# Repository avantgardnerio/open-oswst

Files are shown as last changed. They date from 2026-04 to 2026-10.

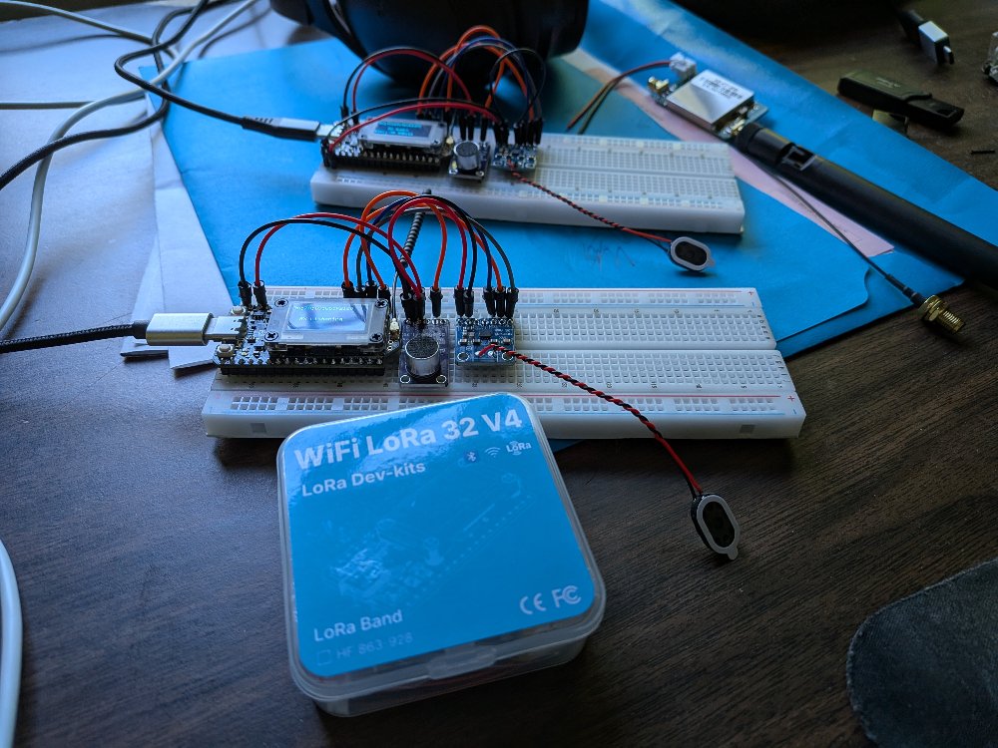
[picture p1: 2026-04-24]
docs/simplex-duo.jpg

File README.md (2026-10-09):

# open-oswst

Stealth LoRa radio mesh where the primary design principle is "only speak when spoken to": a simplex push-to-talk voice radio over
LoRa, with flood repeaters, that transmits nothing until someone presses PTT.

open-oswst radio in 3d printed case

## Hardware

- **Board**: [Heltec WiFi LoRa 32 V4.3](https://heltec.org/project/wifi-lora-32-v4/) (ESP32-S3 + SX1262, 863-928 MHz)
- **MCU**: ESP32-S3 rev 0.2, 16MB flash, ~380 KiB RAM, no PSRAM
- **Radio**: Semtech SX1262 LoRa transceiver, 915 MHz ISM band, behind the board's KCT8103L front-end module (PA + LNA), then an
  external "Air Buddy" amplifier. The SX1262 runs at 6 dBm, which should give roughly 1 W out of the Air Buddy (estimated from datasheets,
  not measured)
- **GPS**: L76K on the Heltec's GNSS connector (UTC time and position, logged and shown on screen)
- **Display**: SSD1306 128x64 OLED (I2C)
- **Audio**: MAX9814 electret mic (ADC), MAX98357A I2S class-D speaker amp

The board is a V4.3. All the boards we've tested are; a V4.2 (GC1109 front end) would need different FEM pins and TX power.

### Pin Map

`src/board.rs` is the one place pins are assigned; this table mirrors it.

| Function | GPIO | Notes |
|---|---|---|
| PTT (PRG button) | 0 | Active LOW, internal pull-up |
| VOL encoder A / B / SW | 3 / 6 / 45 | GPIO45 is a strapping pin, safe as a switch to GND |
| Mic (ADC1) | 4 | MAX9814 out |
| Speaker I2S BCLK / DIN / WS | 47 / 33 / 48 | MAX98357A |
| OLED SDA / SCL / RST | 17 / 18 / 21 | |
| Vext power enable | 36 | LOW = on (OLED) |
| LoRa SCK / MOSI / MISO / NSS | 9 / 10 / 11 / 8 | SPI2 |
| LoRa RST / DIO1 / BUSY | 12 / 14 / 13 | |
| FEM power / enable (CSD) | 7 / 2 | Held HIGH while running |
| FEM CTX | 5 | HIGH only during TX (LOW = RX through the LNA) |
| GPS UART RX / TX | 39 / 38 | ESP side. Meshtastic's variant file comments have these the other way round |
| GPS power / reset / wake | 34 / 42 / 40 | Power is active LOW |
| Battery sense | 1 (+ 37 enables the divider) | Free for this on the newest PCB rev; not used by the firmware yet |

## Dev Environment Setup

### Prerequisites

1. **Install Rust + Xtensa toolchain** via [espup](https://github.com/esp-rs/espup):

```bash
cargo install espup
espup install
```

2. **Create an ESP environment export script** (`~/export-esp.sh`):

```bash
export LIBCLANG_PATH="$HOME/.rustup/toolchains/esp/xtensa-esp32-elf-clang/esp-20.1.1_20250829/esp-clang/lib"
export PATH="$HOME/.rustup/toolchains/esp/xtensa-esp-elf/esp-15.2.0_20250920/xtensa-esp-elf/bin:$PATH"
```

The exact paths may vary — check `~/.rustup/toolchains/esp/` after `espup install`.

3. **Install flashing tools**:

```bash
cargo install espflash cargo-espflash ldproxy
```

4. **Python tools** (log pulling, PCB and case generation) live in a venv built with Python 3.13:

```bash
python3.13 -m venv .venv
.venv/bin/pip install -r requirements.txt
```

### Build

```bash
. ~/export-esp.sh
cargo build                      # firmware (repo root, ESP32-S3)
(cd core && cargo test)          # app logic unit tests, on this PC
(cd desktop && cargo run)        # desktop build (a skeleton so far)
```

ESP-IDF v5.5.x is downloaded automatically by `esp-idf-sys` on first build (takes a while).

### Flash

Over USB, use the script. It flashes every connected board at once, and passes the three things a bare `espflash flash` gets wrong:

```bash
. ~/export-esp.sh && cargo build && scripts/flash-all.sh
```

- **our bootloader** (`--bootloader`): it switches the flash to QIO. espflash's bundled one is DIO
- **our partition table** (`--partition-table`): espflash's default drops the `storage` partition and the OTA slots
- **`--erase-parts otadata`**: otherwise a board last updated over WiFi keeps booting the other slot

Over WiFi, see [In the Field](#in-the-field).

Serial ports aren't stable between plug-ins: identify boards by MAC (the ESP32-S3's USB serial number), not by `ttyACM` number. To capture a
boot log from the first line, `python3 scripts/boot-log.py <PORT>`. Never flash while another program holds the port.

### Device Config

Each board's settings are a text file on its storage: `/data/config.toml`. On the newest PCB rev the on-device menu (click the VOL knob)
sets the mode and rewrites the file. Every setting and flag is declared in `core/src/config.rs`; each boot logs their values
and a 4-digit settings profile (also in `/api/status`): radios with different profiles can't hear each other.

```toml
mode = "repeater"        # normal | repeater | echo

[flags]                  # experiments, come and go (core/src/config.rs lists them)

[[wifi]]                 # networks to join, tried in order
ssid = "Starlink"
password = "..."
```

`scripts/provision.py` writes it over USB, from `boards.toml` in the repo root (kept out of git: it holds WiFi passwords; copy
`boards.example.toml` to start). It flashes the firmware too, and **erases the board's storage**, logs included: pull them first.

```bash
.venv/bin/python scripts/provision.py                      # every connected board
.venv/bin/python scripts/provision.py A4:CB:8F:A2:0F:5C    # just this one
```

The boot log shows the result, e.g. `Config: mode=Echo, 1 WiFi network(s)`.

### Logs

Every boot writes a text log to `/data/log/NNNN.txt` on the board's LittleFS `storage` partition (~11.6 MB). Lines are buffered in RAM and
only written to flash after 3 s with no radio traffic, because a flash write stalls the chip for up to ~18 ms. To copy them off a board:

```bash
.venv/bin/python scripts/pull-logs.py <PORT>     # ~80 s; writes logs/<MAC>-<time>/
```

After an echo test, join the handheld's and the echo station's logs into a per-transmission table and a map (OpenStreetMap/satellite,
one circle per transmission coloured by how well each direction got through, plus GeoJSON for QGIS):

```bash
.venv/bin/python scripts/range-report.py <handheld log> <echo station log>
```

## In the Field

Every radio has the field hotspot (Starlink) in its `config.toml` and stays on WiFi, so in the field the laptop does everything over
WiFi: find the radios, read their status and logs, change their config, update their firmware. USB is the fallback.

### Laptop setup (once, at home)

```bash
sudo apt install avahi-utils curl    # avahi-browse finds the radios; Ubuntu resolves *.local out of the box
```

Plus the build tools above (`espup`, `espflash`, `~/export-esp.sh`), so firmware can be built and saved as an image in the field.

### Find the radios

Join the laptop to the same network as the radios, then:

```bash
avahi-browse -rtp _oswst._tcp | grep "^="    # one line per radio: name, host, IP, port
```

Each radio is `oswst-XXXX.local`, from the last 4 hex digits of its MAC (A4:CB:8F:A2:0F:5C is `oswst-0f5c`). A radio joins WiFi ~7 s
after boot. If a radio doesn't show up:

- `getent hosts oswst-0f5c.local`: asks for one radio by name
- check that avahi-browse ran at all. Don't pipe its errors into grep: if it isn't installed, `2>&1 | grep` prints nothing,
  which looks exactly like "no radios"
- last resort, scan the subnet for the API:
  `for i in $(seq 1 254); do curl -s -m 1 http://192.168.0.$i/api/status | grep -q mac && echo 192.168.0.$i & done; wait`

### Talk to a radio

In a browser: `http://oswst-XXXX.local/` (or its IP) opens the radio's web page, its status and a live picture of its screen
(`www/`, served by the radio itself: no internet needed).

Port 80, no password (the WiFi password is the security). `/fs/` is the radio's storage as a read-write WebDAV folder
(`src/webdav.rs`): open `dav://oswst-XXXX.local/fs/` in a file manager, or:

```bash
R=oswst-0f5c.local
curl http://$R/api/status                     # name, MAC, firmware (git hash, confirmed?), OTA slot, mode, uptime, heap
gio list -l dav://$R/fs/log/                  # after `gio mount dav://$R/fs/`
curl -O http://$R/fs/log/0007.txt             # fetch a log: 25 KB in under 0.1 s (vs ~80 s over USB)
curl -O http://$R/fs/config.toml              # the settings
curl -T config.toml http://$R/fs/config.toml  # replace them (checked first: a bad file is refused); apply on reboot
curl -X POST http://$R/api/reboot
curl -X POST http://$R/api/wifi/off           # WiFi off until the next power cycle (for timing-sensitive tests)
```

`/api/wifi/off` isn't saved: every boot starts with WiFi on again, so a power cycle always gets the radio back on the network. Once it's
off, the radio can't be reached over WiFi until then.

### Update firmware over WiFi (OTA)

Build, save an app image, put it on the radio as `/fs/firmware.bin` (an ordinary file: a file manager works too), then
`POST /api/ota`: the radio copies it into its spare slot and reboots into it (back up in ~15 s). `/api/status` then shows the new
git hash, the other slot and `"firmware_state":"pending"`: a new app must run a minute (then `valid`), or the radio goes back to the
old one. `GET /api/firmware` downloads the app a radio is running.

```bash
. ~/export-esp.sh && cargo build
espflash save-image --chip esp32s3 target/xtensa-esp32s3-espidf/debug/open-oswst app.bin
curl -T app.bin http://oswst-0f5c.local/fs/firmware.bin && curl -X POST http://oswst-0f5c.local/api/ota
```

Every radio found:

```bash
for host in $(avahi-browse -rtp _oswst._tcp | grep "^=" | cut -d';' -f7 | sort -u); do
    curl -T app.bin http://$host/fs/firmware.bin && curl -X POST http://$host/api/ota
done
```

### USB fallback

When a radio isn't on WiFi:

- **Flash:** `scripts/flash-all.sh`. It passes our bootloader, our partition table and `--erase-parts otadata`, which a bare
  `espflash flash` gets wrong.
- **Pull logs:** `scripts/pull-logs.py` (~80 s).
- **Watch a boot:** `scripts/boot-log.py`.

Identify boards by MAC, not by `ttyACM` number, and never flash while another program holds the port.

## Management Server

Radios get updates from a management server (`server/`, issue #34) that they dial out to: nothing on a radio listens for it. Every
connection is Noise: a radio must know the server's public key, and the server must find the radio's in its list, or it's refused.
The server's files live in one folder outside the repo (default `/srv/oswst`):

```
server.key      the server's key pair (mode 0600)
radios.toml     the radios allowed in: re-read at every connection, no restart needed
bundle.tar.gz   THE update: radios that don't have it are offered it
```

```bash
cd server && cargo run --release -- keygen /srv/oswst     # once: prints the server's public key
cd server && cargo run --release -- /srv/oswst            # run it (port 3101)
```

### Publish an update

```bash
scripts/publish-firmware.sh          # builds, then writes /srv/oswst/bundle.tar.gz
```

A bundle (`core/src/bundle.rs`) is one `.tar.gz`: `firmware.bin` for the radio's spare app slot, and `www/` (the web page, with
only the `node_modules` files its import map names) for its storage. The server notices the new file by itself.

### Install it

On the radio: **menu, Update**. It shows the version and size, then **Install** runs three steps, each in percent: **Downloading**
(to the storage), **Verifying** (its SHA-256), **Extracting** (the firmware into the spare slot, marked to boot only once every
file is written; the files onto the storage, never touching `config.toml` or `secrets.toml`). Then it reboots into the new
firmware, which must run a minute to be kept. A radio that has the bundle is told **Up to date**.

`POST /api/management/update` does the same from a laptop. Radios on firmware from before bundles are offered just the firmware
inside the bundle; one more Update then gets the whole bundle.

### Set up a new radio

1. **Provision over USB** (once). Give the radio an entry in `boards.toml` (its mode, name, WiFi networks), then:

   ```bash
   . ~/export-esp.sh && cargo build
   .venv/bin/python scripts/provision.py 10:BD:A3:5A:EB:7C
   ```

   This flashes the firmware and writes a fresh storage holding just its `config.toml` (it **erases** the storage). The radio
   boots, joins WiFi, and makes its own key pair: the private key never leaves it.
2. **Enroll it on the server.** Its public key is on its status page; add it to `/srv/oswst/radios.toml`:

   ```bash
   curl -s http://oswst-eb7c.local/api/status    # "management": {"radio_public_key": "..."}
   ```

   ```toml
   [[radio]]
   name = "Repeater"
   mac = "10:BD:A3:5A:EB:7C"
   public_key = "38389dbc..."
   ```
3. **Tell it where the server is** (and the server's public key, from `keygen`):

   ```bash
   curl -X PUT -H "Content-Type: application/json" \
        -d '{"host": "<server host>", "port": 3101, "server_public_key": "<64 hex digits>"}' \
        http://oswst-eb7c.local/api/management
   ```
4. **Menu, Update.** A radio flashed over USB doesn't have the bundle yet, so it's offered it: that brings the web page too.

A re-provisioned radio has a new key (the storage was erased), so it's enrolled again: replace its `public_key` in `radios.toml`.
To shut a lost radio out, delete its entry.

## Current Behavior

- **Voice**: simplex push-to-talk. Hold PTT to talk: audio is Codec2-encoded at 1200 bps and streamed as 4-frame LoRa packets (160 ms of
  audio each, SF7/125 kHz). Release to listen: received packets are decoded in order and played through the speaker. A lost packet
  costs one 160 ms gap of silence, and a corrupt one is dropped rather than resetting playback. PTT does nothing while someone else's
  transmission is on the air: no talking over each other
- **Modes**: normal; **repeater** (relays the first copy of each packet once, one hop further: flood style, but a copy that loops back
  is a duplicate); **echo** (records a transmission, then plays it back over the air, for range testing alone). Set in
  `/data/config.toml`
- **Screen**: short MAC and UTC time, GPS position, RX/TX state, RSSI and SNR of received audio, and volume
- **Controls**: VOL knob turns volume; clicking it opens the menu (Lock, Mode). Needs the newest PCB rev's wiring (see Pin Map)
- **Logs**: persistent per-boot text logs including a GPS fix every 30 s, so field tests can be mapped afterwards
- **Timing**: the air is a conveyor of 80 ms bins (`core/src/conveyor.rs`). A talker sends packet n in bin 2n and each repeater relays
  it one bin later, so hop h of packet n is in bin 2n + h; the header's hop count says which. Every packet starts at its microsecond, in
  the middle of its bin (the radio sends it then). A receiver counts bins from the first good packet it hears, so every copy of a packet
  is the same packet, and a garbled packet in a bin still keeps the transmission going. Only a talker's first packet waits for clear air
- **Listening**: during a transmission the radio turns through a schedule of channels, bin by bin (`core/src/climb.rs`): it holds the
  channel with the strongest copies in their bins, and in the others always seeks one channel on and one back. A side that's clearly
  stronger becomes the hold, so a listener climbs to the best copy of several repeaters'. Only the first copy of each packet plays
- **Next up**: frequency hopping and encryption

<!-- air-diagram: generated by scripts/air-diagram.py; edit the script, not this section -->
## On the Air (SF7 / 125 kHz)

LoRa SF7, 125 kHz, coding rate 4/5, explicit header, 12-symbol preamble (`core/src/air.rs`). One symbol is 2^7 / 125 kHz =
**1.024 ms**. Air times are Semtech's formula on our constants; regenerate this section with `python3 scripts/air-diagram.py`
after changing one.

### Voice packet: 26 bytes, 64.25 symbols, 65.8 ms

```
symbol 0           12     16.25   24.25                                   64.25
       +-----------+------+-------+----+----+----+----+----+----+----+----+
       |  preamble | sync |  PHY  | B1 | B2 | B3 | B4 | B5 | B6 | B7 | B8 |
       |   12 sym  | 4.25 | header|            8 blocks x 5 sym           |
       |           | sym  | 8 sym |        28 bits each = 224 bits        |
       |           |      |       |        = 26 B payload + 2 B CRC       |
       +-----------+------+-------+----+----+----+----+----+----+----+----+
ms     0           12.3   16.6    24.8                                    65.8
```

- **sync**: 2 sync-word symbols + 2.25 start-of-frame symbols
- **CRC**: ours (`core/src/crc.rs`, CRC-16/CCITT-FALSE), appended and checked by the radio driver, with LoRa's own CRC off: the
  same 16 bits on the air. LoRa only checks its CRC if the received header says there is one, and noise can corrupt a header
  into "no CRC" and still pass its checksum; ours is checked on every packet, so garbage never reaches the app
- **PHY header**: 20 bits (payload length, coding rate, CRC flag (off), header checksum), always sent at CR 4/8: 8 symbols (at
  SF7, nothing else fits)
- **blocks**: each 5-symbol block carries 28 data bits. 26 bytes + CRC fill 8 blocks exactly; one more byte costs another block
  (+5 symbols, +5.1 ms)

The 26 bytes:

```
byte   0               2           8           14          20          26
       +---------------+-----------+-----------+-----------+-----------+
       |   our header  |   Codec2  |   Codec2  |   Codec2  |   Codec2  |
       |   (2 bytes)   |  frame 1  |  frame 2  |  frame 3  |  frame 4  |
       |               |  6 bytes  |  6 bytes  |  6 bytes  |  6 bytes  |
       |               |  = 40 ms  |  = 40 ms  |  = 40 ms  |  = 40 ms  |
       +---------------+-----------+-----------+-----------+-----------+

our header, 16 bits, big-endian (core/src/packet.rs):
bit     15     11 10          4 3       1 0        0
       +---------+-------------+---------+----------+
       | type 5b |   txid 7b   | hops 3b | spare 1b |
       +---------+-------------+---------+----------+
       type: 0 voice, 1 echo replay, 2 wake, 3 voice end, 4 echo end (core/src/packet.rs PacketType)
       txid: random per transmission; hops: repeaters this copy came through, 0 from the talker; spare: 0
```

### Wake packet: 2 bytes, 64.25 symbols, 65.8 ms

Sent once, first, so radios sweeping the hop channels can find the transmission. The preamble takes up the air the audio would
have used, so it fits a slot like any packet: 12 + (48 − 18) = 42 symbols.

```
symbol 0                                         42     46.25   54.25     64.25
       +-----------------------------------------+------+-------+----+----+
       |                 preamble                | sync |  PHY  | B1 | B2 |
       |      42 sym: a sweeping radio's CAD     | 4.25 | header| 2 B hdr |
       |      (2 sym) can land in the first      | sym  | 8 sym |  + CRC  |
       |            40 symbols (41 ms)           |      |       |         |
       +-----------------------------------------+------+-------+----+----+
ms     0                                         43.0   47.4    55.6      65.8
```

### End packet (EOT): 26 bytes, 64.25 symbols, 65.8 ms

The last packet of every transmission says who sent it and where they were: a voice packet's size and air, so it fits a
repeater's slot like one. The talker sends its own; a repeater relays it unchanged; an echo station ends its replay with its
own. The screen shows who was last heard, how far away, and through a repeater or not.

```
byte   0               2           5           8                                26
       +---------------+-----------+-----------+--------------------------------+
       |  our header   | latitude  | longitude |  name, UTF-8, up to 18 bytes   |
       | type 3 or 4   | 24 bits   | 24 bits   |          zero-padded           |
       +---------------+-----------+-----------+--------------------------------+
       latitude: ±90° in ±2^23 steps (~1.2 m); longitude: ±180° (~2.4 m); -2^23 latitude = no fix
```

### A transmission

```
PTT pressed
 +160 ms   wake packet         64.25 sym   (sent while the first 160 ms of audio is captured)
 ~320 ms   voice packet 0      64.25 sym   then one voice packet every 160 ms (156.25 sym)
     ...
 release   last voice packet, then EOT    64.25 sym  (who and where)
```

An echo station sends its wake packet one slot before its replay. A repeater relays a wake packet like any other (once per
transmission), so radios that only hear the repeater can find it.

### One slot with a repeater: 160 ms = 156.25 symbols

Talkers don't hop yet (`tx_hops = 0`): every transmission stays on the start slot, channel 0. Receivers sweep `rx_hops`
channels, and with the sweep flag a repeater relays each packet on the next of those after the one it heard it on (channel 1
here), then goes back to listening on channel 0. It relays as soon as it has the packet, inside the gap before the talker's next
one. Repeater steps are medians of 226 relays (the talker's packets and the echo station's replays) measured on the desk
(`out/relay-test/20261005-150052`).

```
symbol    0                               64.25                                137      156.25
          |                               |                                    |        |
talker    [=== voice packet n ============]                                             [== packet n+1
repeater   . RX (locked) .................]ttt[===== relay of packet n ========]b. RX ..[
                                           ^ t: RX done -> relay on air 7.8 ms
                                                                                ^ b: back to RX 1.5 ms
                                                                                <-- slack 17.9 ms -->
ms        0                               65.8                                 140.6    160
```

| Step (repeater) | Median | Symbols | |
|---|---|---|---|
| RX done → relay starts | 5.4 ms | 5.2 | `t`: read the packet out, the app hands it back to the radio |
| standby | 0.9 ms | 0.8 | `t` |
| prep (packet, modulation, buffer) | 1.5 ms | 1.5 | `t` |
| tx: TX command → TxDone | 67.1 ms | 65.5 | 65.8 ms on the air + PA ramp and IRQ |
| back to RX | 1.5 ms | 1.5 | `b` |
| **slack before packet n+1** | **17.9 ms** | **17.5** | a relay ending later than this deafens the repeater to the next packet |

Each repeater uses ~142 of the 160 ms. A second repeater in the chain can't fit the same slot on the same channel; that's what
hopping (each repeater relays on the next channel) is for.
<!-- /air-diagram -->

## Key Implementation Notes

- **Framework**: esp-idf-svc 0.52.1 (std Rust, not bare-metal)
- **Async**: `block_on` + `embassy_futures::select`; the app sleeps until an event (packet, PTT, speaker, knob) or a 250 ms housekeeping tick
- **LoRa driver**: `lora-phy` (lora-rs git main) with `GenericSx126xInterfaceVariant`; DIO2 drives the FEM's TX/RX path, GPIO5 its RX LNA
- **Hardware-free app**: everything above the drivers is in `core/` behind small device traits, so it runs and is tested on a PC
- **Storage**: LittleFS (`joltwallet/littlefs` component) mounted at `/data`, chosen over FAT for power-cut safety
- **SPI async**: `CONFIG_SPI_MASTER_ISR_IN_IRAM` disabled in `sdkconfig.defaults`
- **defmt workaround**: `defmt-discard.x` linker script discards defmt sections that break ESP-IDF flash layout
- **Stack**: 65536 bytes for main task (Codec2 init needs large stack temporaries)

## Project Structure

Four Cargo workspaces. Each opens as its own IDE project: the firmware builds for the ESP32-S3, the others for this PC.

```
src/                 # Firmware (repo root workspace, xtensa)
  main.rs            #   Brings up the board and runs the core app on it
  board.rs           #   The one place pins are assigned
  devices/           #   ESP drivers: radio, fem, gps, mic, speaker, screen, encoder, ptt, settings, storage
  bin/               #   Bringup tests (fem_probe, gps_test, storage_test, batt_probe, loopbacks, ...)
core/                # Hardware-free app: its own workspace, so `cargo test` runs on this PC
  src/app.rs         #   Event loop, screens, housekeeping
  src/conveyor.rs    #   A transmission's bins: which packet each copy is, when it's over (unit tested)
  src/climb.rs       #   Which channel to listen on, bin by bin: hold the strongest copy, seek beside it (unit tested)
  src/playout.rs     #   Decoded packets to the speaker in order, silence for lost ones (unit tested)
  src/codec.rs       #   Codec2 thread
  src/management.rs  #   The management server's protocol (Noise), shared with server/
  src/bundle.rs, tar.rs, gzip.rs   # Update bundles: what goes where, streamed off a .tar.gz (unit tested)
  src/echo.rs, mode.rs, menu.rs, packet.rs, logger.rs
  src/devices/       #   Device interfaces: radio/speaker/screen channels, gps/mic/ptt/knob/settings traits
desktop/             # Desktop build on virtual devices (skeleton so far)
server/              # The management server: radios' keys, update bundles
www/                 # The radio's web page (preact + htm, no build step), shipped in bundles
scripts/             # provision.py, publish-firmware.sh, boot-log.py, pull-logs.py, ...
pcb/                 # PCB definition (Python DSL) and generated KiCad board
models/              # Parametric case (build123d) and fit check
partitions.csv       # Partition table: two OTA app slots, LittleFS storage (/data)
boards.example.toml  # Per-board settings for scripts/provision.py (copy to boards.toml)
sdkconfig.defaults   # ESP-IDF config overrides
```

## Bill of Materials

### Handset (~$122)

| Component | Part | Qty | Est. Cost |
|---|---|-----|---|
| [MCU + LoRa + GPS](https://www.amazon.com/dp/B0GCD9W6JZ?ref=ppx_yo2ov_dt_b_fed_asin_title&th=1) | Heltec WiFi LoRa 32 V4 | 1 | $42 |
| [RF amplifier](https://www.amazon.com/dp/B0DQBJVR91?ref=ppx_yo2ov_dt_b_fed_asin_title) | AB-IOT-868 "Air Buddy" (902-928 MHz, bidirectional TX+LNA) | 1 | $26 |
| [Speaker amp](https://www.amazon.com/dp/B0DPJRLMDJ?ref=ppx_yo2ov_dt_b_fed_asin_title) | MAX98357A I2S Class D breakout | 1 | $3 |
| [Speaker](https://www.amazon.com/dp/B0BTP67F81?ref=ppx_yo2ov_dt_b_fed_asin_title&th=1) | 8 ohm 1W mini (JST-PH1.25mm) | 1 | $2.50 |
| [Microphone](https://www.amazon.com/dp/B0B7SP6GYX?ref=ppx_yo2ov_dt_b_fed_asin_title) | MAX9814 electret with AGC (analog out) | 1 | $4 |
| [Antenna](https://www.amazon.com/dp/B0D47HVCK7?ref=ppx_yo2ov_dt_b_fed_asin_title&th=1) | 5 dBi SMA whip (915 MHz) | 1 | $6 |
| [Battery](https://www.amazon.com/dp/B0FPCWFFYB?ref=ppx_yo2ov_dt_b_fed_asin_title) | YELUFT 1S 103450 3.7V 2000mAh LiPo (JST 1.25) | 1 | $24 |
| [encoder](https://www.amazon.com/dp/B07F24TRYG?ref=ppx_yo2ov_dt_b_fed_asin_title) | EC11 rotary encoder w/ push button (Taiss) | 2 | $1.25 |
| [Power switch](https://www.amazon.com/dp/B0DN69L9SG?ref=ppx_yo2ov_dt_b_fed_asin_title&th=1) | SS12F15 mini slide switch (SPDT) | 1 | $0.30 |
| [PTT button](https://www.amazon.com/dp/B015X34IP6?ref=ppx_yo2ov_dt_b_fed_asin_title&th=1) | Ulincos U16A1 16mm metal momentary, flush | 1 | $8 |
| [Speaker jack](https://www.amazon.com/dp/B01ASF0LW8?ref=ppx_yo2ov_dt_b_fed_asin_title) | 2.5mm TRS chassis mount (Calrad 30-714 or similar) | 1 | $0.66 |
| [Mic/PTT jack](https://www.amazon.com/dp/B00ZYWJ1DG?ref=ppx_yo2ov_dt_b_fed_asin_title) | 3.5mm TRS chassis mount w/ switch (CESS) | 1 | $2 |
| [F2F SMA](https://www.amazon.com/dp/B0FB3R5WRL?ref=ppx_yo2ov_dt_b_fed_asin_title&th=1) | Female to Female SMA | 1 | $1 |

## Related Projects

Voice over LoRa is rare. This is what we found as of October 2026, with our own status stated the same way as everyone else's.

| Project | What it does | Repeating | Licence | Status |
|---|---|---|---|---|
| **open-oswst** (this) | Live push-to-talk, Codec2 1200 bps, handheld with case and PCB | Flood repeater mode exists, but more than one repeater degrades audio; making multi-repeater flooding work is the current focus | None (US 902–928 MHz ISM) | Live voice works handheld to handheld; field-tested to ~600 m through suburbs (GPS-logged). No encryption or frequency hopping yet |
| [QMesh](https://github.com/faydr/QMesh) ([project](https://hackaday.io/project/161491-qmesh-a-lora-based-voice-mesh-network), [paper](https://cdn.hackaday.io/files/1614916909230944/TAPR%20DCC%202020%20Paper.pdf)) | Live voice, Codec2, 160 ms frames | **Synchronised flooding:** every node retransmits at once in TDMA slots, with extra FEC and deliberate timing/frequency offsets so the copies don't destructively collide, plus per-packet hopping. Reported 99% packet reception with 2–3 simultaneous retransmitters | Amateur (US Technician) | **Ahead of us on radio techniques.** STM32 dev boards + custom shield. No commits since December 2022 |
| [Mesh-Talkie](https://github.com/WIH4/Mesh-Talkie) | Planned PTT handheld, ESP32-S3 + SX1262 (our hardware), AES-256 | Planned flood mesh with TTL | None (EU SRD) | Design documents only: no hardware or firmware yet |
| [esp32_loradv](https://github.com/sh123/esp32_loradv) | Codec2/Opus digital-voice walkie-talkie | None (point to point) | Amateur (70 cm) | Hobby project |
| Meshtastic, [MeshCore](https://github.com/RipeStore/meshcorebuilder), [MeshTRX](https://github.com/StanislavButkovsky/meshtrx) | Text mesh messengers | Yes, for text | None | Mature for text; voice is recorded clips forwarded later, not live PTT |
| [dudmuck/lora_codec2](https://github.com/dudmuck/lora_codec2), [Lora-Voice-Image-Text](https://github.com/chicodog530/Lora-Voice-Image-Text), [ESP32_Codec2](https://github.com/deulis/ESP32_Codec2) | Codec2-over-LoRa demos | None | — | Demos |

As far as we can tell, nobody else has live push-to-talk voice over LoRa working on handhelds **without a licence**. The hard part, several repeaters sharing one channel, is unsolved here; QMesh has gone furthest on it, and under an amateur licence.

## License

TBD

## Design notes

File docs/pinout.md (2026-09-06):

# Heltec WiFi LoRa 32 V4 — Pinout Reference

Transcribed from `docs/WiFi_LoRa_32_V4.2.0.pdf` (Rev 1.4, Sep 2025), §2 Pin Definition.
Board: ESP32-S3R2 + SX1262, 51.7 × 25.4 × 10.7mm, 2× 18-pin 2.54mm headers.

## Orientation

**Pin 1 of both headers is at the USB-C end.** Pin 18 is at the antenna/OLED end.
Viewed from the front (OLED facing you, USB-C down): **J3 is the left row, J2 is the right row.**

Confirmed empirically during bringup 2026-09-05, and matches the pin-layout figure on p.7.

> ⚠️ **Bench-wiring hazard.** J2 pin 1 is GND but **pin 2 is 5V**. An off-by-one on J2 puts 5V
> through your circuit onto a 3.3V-max GPIO. J3 is safer for hand-wiring — its pin 1 neighbors
> are 3V3. Symptom of getting this wrong: the OLED blanks on button press (rail brownout).
> Confirm the ground pin by continuity to the USB-C shell before powering on.

## Header J3 (left row)

| Pin | GPIO | Analog/RTC | Special function |
|---:|---|---|---|
| 18 | GPIO7 | ADC1_CH6, TOUCH7 | **V_FEM_Control** |
| 17 | GPIO6 | ADC1_CH5, TOUCH6 | — |
| 16 | GPIO5 | ADC1_CH4, TOUCH5 | — |
| 15 | GPIO4 | ADC1_CH3, TOUCH4 | — |
| 14 | GPIO3 | ADC1_CH2, TOUCH3 | — (⚠️ ESP32-S3 strapping: JTAG source select) |
| 13 | GPIO2 | ADC1_CH1, TOUCH2 | figure says `FEM_EN`, table does not — see note below |
| 12 | GPIO1 | ADC1_CH0, TOUCH1 | **VBAT_Read** ¹ |
| 11 | GPIO38 | — | GNSS_RX (FSPIWP, SUBSPIWP) |
| 10 | GPIO39 | — | GNSS_TX (MTCK) |
| 9 | GPIO40 | — | GNSS_Wakeup (MTDO) |
| 8 | GPIO41 | — | GNSS_PPS (MTDI) |
| 7 | GPIO42 | — | GNSS_RST (MTMS) |
| 6 | GPIO45 | — | ⚠️ ESP32-S3 strapping (VDD_SPI select) |
| 5 | GPIO46 | — | ⚠️ ESP32-S3 strapping (boot mode) |
| 4 | GPIO37 | — | **ADC_Ctrl** (SPIDQS, FSPIQ, SUBSPIQ) |
| 3 | 3V3 | Power | 3.3V supply ² |
| 2 | 3V3 | Power | 3.3V supply ² |
| 1 | GND | Ground | — |

¹ Per datasheet footnote: ADC1_CH0 reads the lithium battery voltage; **ADC_CTRL (GPIO37) must be
pulled high** to enable it. `VBAT = 100 / (100+390) * VADC_IN1`. Because it is gated, GPIO1 is
usable as an ordinary input — verified working as a button input 2026-09-05.

² ⚠️ J3 3V3 is a **2.7–3.5V input/output rail**. Never feed it raw LiPo. See the power notes.

### Note: GPIO2, FEM_EN, and a false alarm

Heltec's document disagrees with itself about GPIO2:

- The **pin-layout figure (p.7)** labels GPIO2 as **`FEM_EN`** (and separately labels GPIO7 as
  `VFEM_Ctrl`).
- The **pin-description table (p.9)** lists GPIO2 as only `ADC1_CH1, TOUCH2` — **no FEM_EN** —
  while it does list `V_FEM_Control` on GPIO7. That table names every other special function in
  red (GNSS_*, VBAT_Read, ADC Ctrl), so the omission is conspicuous.

**GPIO2 is usable as an ordinary pulled-up input.** Verified 2026-09-06 on a healthy board
(MAC `F8:5B:1B:A2:C6:2C`): a rotary encoder on GPIO3/2/1 produces all four quadrature states
and a correctly accumulating count.

The confusion arose because one board (MAC `90:70:69:85:F2:50`) reads GPIO2 **stuck low** — 240
transitions, never rising, even with nothing connected and `Pull::Up` set. That board had
survived a power-rail short from a mis-wired header hours earlier; the pin is damaged. The p.7
`FEM_EN` label made a plausible-sounding root cause for what was simply a dead input.

**Lesson: reproduce a pin failure on a second board before treating it as a design constraint.**
Note too that GPIO7 — which the table says carries FEM control — works fine as a pulled-up input,
so a FEM-related function does not by itself make a pin unusable.

## Header J2 (right row)

| Pin | GPIO | Analog/RTC | Special function |
|---:|---|---|---|
| 18 | GPIO19 | Analog, RTC | ⚠️ **USB_D-** (U1RTS, ADC2_CH8) |
| 17 | GPIO20 | Analog, RTC | ⚠️ **USB_D+** (U1CTS, ADC2_CH9) |
| 16 | GPIO21 | RTC | **OLED_RST** |
| 15 | GPIO26 | — | ⚠️ SPICS1 (SPI flash region) |
| 14 | GPIO48 | — | SPICLK_N_DIFF, SUBSPICLK_N_DIFF |
| 13 | GPIO47 | — | SPICLK_P_DIFF, SUBSPICLK_P_DIFF |
| 12 | GPIO33 | — | SPIIO4, FSPIHD, SUBSPIHD |
| 11 | GPIO34 | — | **VGNSS_Ctrl** (SPIIO5, FSPICS0) |
| 10 | GPIO35 | — | **LED** (SPIIO6, FSPID) |
| 9 | GPIO36 | — | **Vext_Ctrl** (SPIIO7, FSPICLK) — LOW = peripherals on |
| 8 | GPIO0 | — | **PRG button** |
| 7 | RST | Input | CHIP_PU, reset button |
| 6 | GPIO43 | — | ⚠️ U0TXD (serial console) |
| 5 | GPIO44 | — | ⚠️ U0RXD (serial console) |
| 4 | Ve | Power | 3.3V output (gated by Vext_Ctrl) |
| 3 | Ve | Power | 3.3V output (gated by Vext_Ctrl) |
| 2 | **5V** | Power | ⚠️ 5V supply |
| 1 | GND | Ground | — |

## Not on the headers

**LoRa (SX1262), internal:**

| GPIO | Function | GPIO | Function |
|---|---|---|---|
| GPIO8 | LoRa_NSS | GPIO12 | LoRa_RST |
| GPIO9 | LoRa_SCK | GPIO13 | LoRa_BUSY |
| GPIO10 | LoRa_MOSI | GPIO14 | DIO1 |
| GPIO11 | LoRa_MISO | | |

**Additional pins (§2.2.3):** GPIO18 = OLED_SCL · GPIO17 = OLED_SDA ·
GPIO16 = XTAL_32K_N · GPIO15 = XTAL_32K_P

**GNSS connector (SH1.25, 8-pin):** GND · GPIO34 (VGNSS_Ctrl) · 3V3 · GPIO39 (GNSS_TX) ·
GPIO38 (GNSS_RX) · GPIO40 (GNSS_Wakeup) · GPIO41 (GNSS_PPS) · GPIO42 (GNSS_RST)

## Our assignments (`pcb/board.py`)

| Net | GPIO | J3 pin | Status |
|---|---|---:|---|
| CHNL_A | GPIO7 | 18 | ✅ verified |
| CHNL_B | GPIO6 | 17 | ✅ verified |
| CHNL_SW | GPIO5 | 16 | ✅ verified on a bare Heltec; rev4 board has a solder bridge |
| MIC_OUT | GPIO4 | 15 | ADC1_CH3 |
| VOL_A | GPIO3 | 14 | ✅ verified |
| VOL_B | GPIO2 | 13 | ✅ verified (see GPIO2 note — one damaged board caused a false alarm) |
| VOL_SW | GPIO1 | 12 | ✅ verified |

| Net | GPIO | J2 pin |
|---|---|---:|
| LRC | GPIO48 | 14 |
| BCLK | GPIO47 | 13 |
| DIN | GPIO33 | 12 |
| PTT | GPIO0 | 8 |
| Ve | Ve | 3, 4 |

J3 3V3 (pins 2/3) is deliberately **left disconnected** — wiring it would back-feed the regulated
rail. J2 5V (pin 2) is likewise disconnected. See the power architecture notes.

**Free for reassignment:** GPIO38–42 (J3 pins 11–7, currently reserved for GNSS) and GPIO26
(J2 pin 15, SPI-flash region — risky). Avoid GPIO45/46 (strapping) and GPIO34/35/36 (driven
by the Heltec).

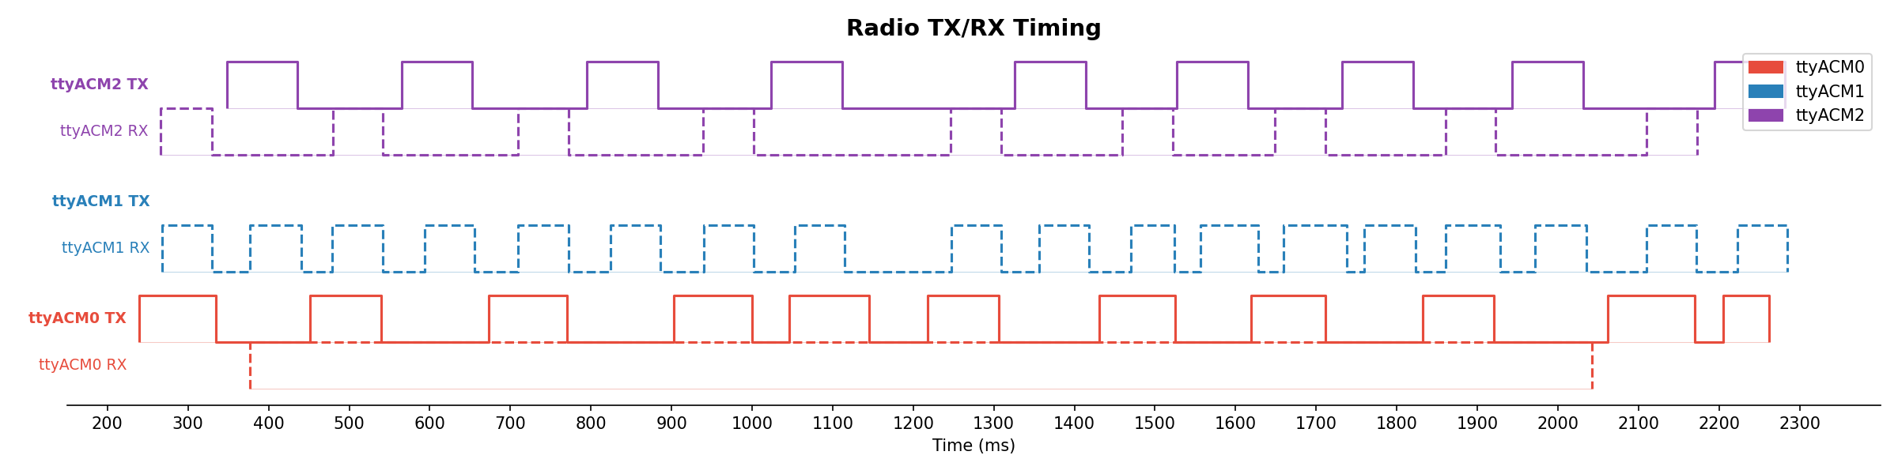
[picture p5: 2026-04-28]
timing.png

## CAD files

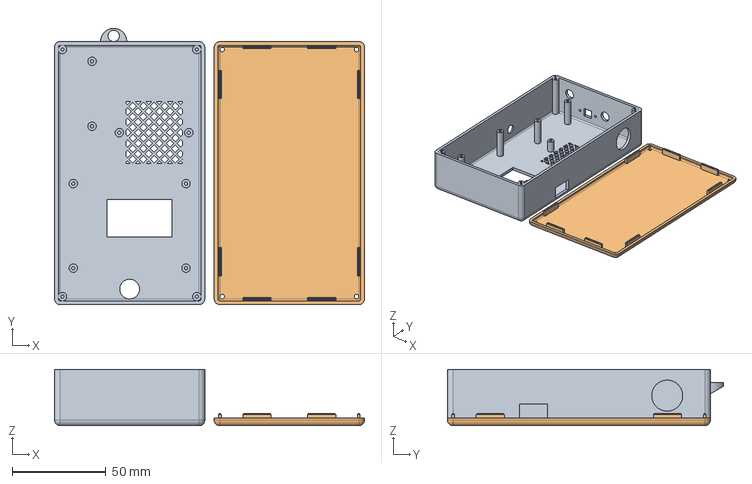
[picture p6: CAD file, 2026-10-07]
models/case.step
165.0 x 147.0 x 30.0 mm

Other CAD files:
models/case.stl

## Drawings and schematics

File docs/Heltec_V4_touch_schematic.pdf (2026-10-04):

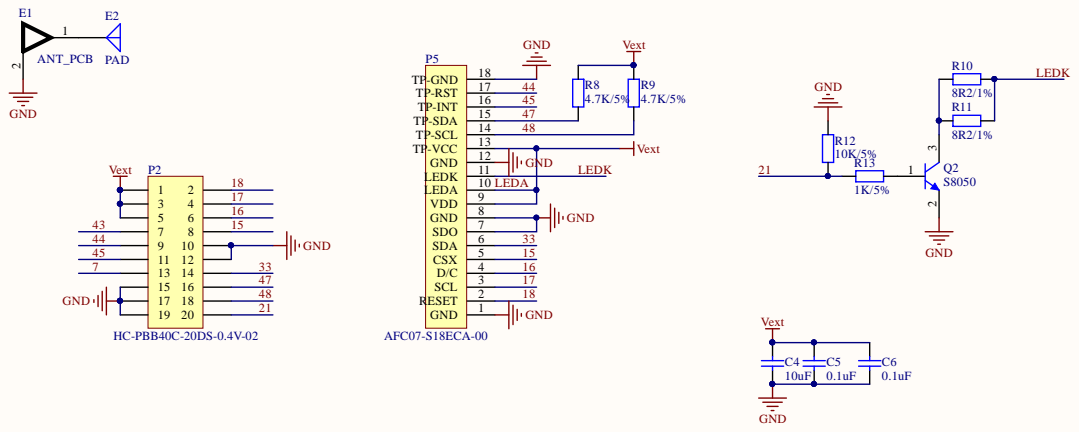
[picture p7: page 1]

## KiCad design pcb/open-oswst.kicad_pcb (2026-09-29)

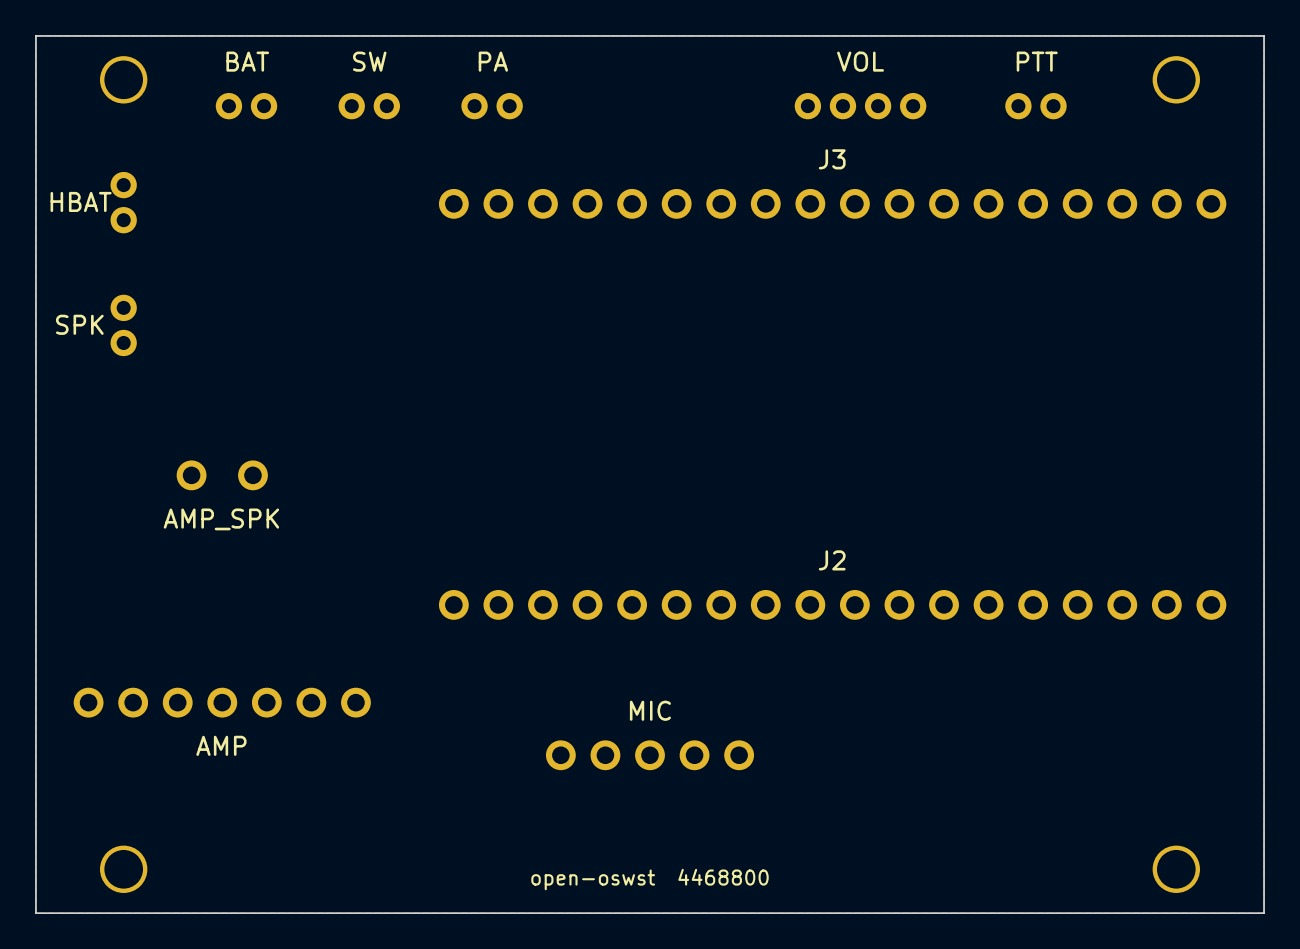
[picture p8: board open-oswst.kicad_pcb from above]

Board: 2 copper layers, 70.0 x 50.0 mm, 16 parts (0 on the bottom side), 14 nets, no tracks yet.

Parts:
AMP: PinHeader_1x7_P2.54mm
AMP_SPK: PinHeader_1x2_P3.5mm
BAT: JST_PH_B2B
H1, H2, H3, H4: MountingHole_2.2mm
HBAT: JST_PH_B2B
J2, J3: PinHeader_1x18_P2.54mm
MIC: PinHeader_1x5_P2.54mm
PA: JST_PH_B2B
PTT: JST_PH_B2B
SPK: JST_PH_B2B
SW: JST_PH_B2B
VOL: JST_PH_B4B

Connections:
BCLK: AMP.BCLK, J2.GPIO47
DIN: AMP.DIN, J2.GPIO33
GND: AMP.GND, BAT.-, HBAT.-, J2.GND, J3.GND, MIC.GND, PA.-, PTT.2, VOL.GND
LRC: AMP.LRC, J2.GPIO48
MIC_OUT: J3.GPIO4, MIC.OUT
PTT: J2.GPIO0, PTT.1
SPK+: AMP_SPK.+, SPK.+
SPK-: AMP_SPK.-, SPK.-
VBAT: BAT.+, SW.1
VOL_A: J3.GPIO3, VOL.A
VOL_B: J3.GPIO6, VOL.B
VOL_SW: J3.GPIO45, VOL.SW
VSW: HBAT.+, PA.+, SW.2
Ve: AMP.Vin, J2.Ve_a, J2.Ve_b, MIC.VDD

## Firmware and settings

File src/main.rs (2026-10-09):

//! Firmware entry point: brings up the board's hardware and runs the app from
//! the core crate on it. Everything radio-behaviour lives in core.

use core::fmt::Write as _;
use embassy_futures::join::join4;
use esp_idf_svc::hal::cpu::Core;
use esp_idf_svc::hal::task::block_on;
use open_oswst::devices::{
    battery, encoder, fem, gps, mic, ptt, radio, screen, settings, speaker, storage,
};
use open_oswst::{board, firmware, net, thread};
use open_oswst_core::devices::network::Network;
use open_oswst_core::platform::Platform;
use open_oswst_core::{air, app, codec, config, logger};
use std::path::{Path, PathBuf};

/// The radio thread's priority: above the codec's (5), so the codec can't
/// delay a TX or an IRQ, and below the hal's IsrReactor (11), which wakes it.
const RADIO_PRIORITY: u8 = 10;

/// The app and speaker (this, the main task, on core 0). The main task starts
/// at 1, below everything: the codec, screen, GPS and HTTP server (5) could
/// all delay the speaker. Now level with the radio, which is on the other
/// core; only WiFi and the hal's IsrReactor (11) come first.
const APP_PRIORITY: u8 = 10;

/// The board, as the app sees it
struct Esp;

impl Platform for Esp {
    type Mic = mic::Mic;
    type Battery = battery::Battery;
    type Ptt = ptt::Ptt;
    type Knob = encoder::Encoder;
    type Gps = gps::Gps;
    type Settings = settings::Settings;

    fn random() -> u32 {
        unsafe { esp_idf_svc::sys::esp_random() }
    }

    fn now_us() -> i64 {
        unsafe { esp_idf_svc::sys::esp_timer_get_time() }
    }

    fn network() -> Network {
        net::state()
    }

    fn data_dir() -> Option<PathBuf> {
        storage::mounted().then(|| PathBuf::from(storage::ROOT))
    }
}

/// Read the base MAC address from eFuse
fn get_mac() -> [u8; 6] {
    let mut mac = [0u8; 6];
    unsafe {
        esp_idf_svc::sys::esp_read_mac(
            mac.as_mut_ptr(),
            esp_idf_svc::sys::esp_mac_type_t_ESP_MAC_WIFI_STA,
        );
    }
    mac
}

/// Log lines waiting for the file, in PSRAM: minutes of talking at the
/// ~1-2KB/s a busy radio logs (2026-10-08 logs), against ~10s in the 16KB of
/// internal RAM it had before
const LOG_BUFFER_BYTES: usize = 1024 * 1024;
/// Without PSRAM (a board that has none): what the internal heap can spare
const LOG_BUFFER_FALLBACK_BYTES: usize = 16 * 1024;

/// The log buffer's memory, once, for good. Only this explicit request puts
/// anything in PSRAM (CONFIG_SPIRAM_USE_CAPS_ALLOC): ordinary allocations
/// never land there. Returns whether it got PSRAM.
fn log_buffer_memory() -> (&'static mut [u8], bool) {
    use esp_idf_svc::sys::{heap_caps_malloc, MALLOC_CAP_8BIT, MALLOC_CAP_SPIRAM};
    let memory = unsafe { heap_caps_malloc(LOG_BUFFER_BYTES, MALLOC_CAP_SPIRAM | MALLOC_CAP_8BIT) };
    if memory.is_null() {
        let fallback = vec![0u8; LOG_BUFFER_FALLBACK_BYTES].into_boxed_slice();
        return (Box::leak(fallback), false);
    }
    // SAFETY: a fresh allocation of that many bytes, never freed, so 'static
    let memory = unsafe { std::slice::from_raw_parts_mut(memory as *mut u8, LOG_BUFFER_BYTES) };
    (memory, true)
}

fn main() {
    esp_idf_svc::sys::link_patches();
    // Same clock as ESP-IDF's own log lines
    let (log_buffer, in_psram) = log_buffer_memory();
    let log_buffer_bytes = log_buffer.len();
    logger::init(
        || unsafe { esp_idf_svc::sys::esp_log_timestamp() },
        log_buffer,
    );
    // ESP-IDF's own boot lines print its version, which goes stale
    // (firmware.rs VERSION): this one is the build's
    log::info!("open-oswst {} starting...", firmware::version());
    if in_psram {
        log::info!("Log buffer: {} KB in PSRAM", log_buffer_bytes / 1024);
    } else {
        log::warn!(
            "No PSRAM: log buffer {} KB of internal RAM",
            log_buffer_bytes / 1024
        );
    }

    // The settings (and the log files) live on the storage
    let storage_ok = match storage::init() {
        Ok(()) => true,
        Err(e) => {
            log::warn!("Storage unavailable ({}), serial only", e);
            false
        }
    };

    let board = board::take();
    let _fem = fem::init(board.fem);
    let gps = gps::init(board.gps);

    // After storage: the settings are a file on it
    let settings = settings::init();
    config::load(Some(&settings));

    // Logs also go to a file per boot, unless log_to_flash is off: then
    // nothing from logging ever writes the flash (the menu switches it, at
    // once). Started only now that the settings say; the lines logged before
    // wait in the RAM buffer
    if storage_ok {
        logger::set_storage(&Path::new(storage::ROOT).join("log"), storage::usage);
        if config::LOG_TO_FLASH.is_on() {
            match logger::start_file() {
                Ok(path) => log::info!("Logging to {}", path.display()),
                Err(e) => log::warn!("No log file ({}), serial only", e),
            }
        } else {
            log::info!("Not logging to flash (log_to_flash off): serial only");
            logger::stop_file();
        }
    } else {
        logger::stop_file();
    }
    log::info!(
        "Config: {} WiFi network(s)",
        settings::wifi_networks().len()
    );
    let settings = Some(settings);

    // Get MAC for display
    let mac = get_mac();
    let mut mac_str = heapless::String::<18>::new();
    let _ = core::fmt::write(
        &mut mac_str,
        format_args!(
            "{:02X}:{:02X}:{:02X}:{:02X}:{:02X}:{:02X}",
            mac[0], mac[1], mac[2], mac[3], mac[4], mac[5]
        ),
    );

    // Spawn codec thread with sync channel (capacity 2 to allow pipelining)
    let (codec_tx, codec_rx) = std::sync::mpsc::sync_channel::<codec::CodecRequest>(2);
    // ~25.6KB used at worst (Stack free log, 2026-10-02): Codec2 is deep.
    // On core 1, away from the app, speaker and WiFi on core 0. The radio is
    // there too, but above it (10 vs 5), and mostly waiting
    thread::spawn(c"codec", 32768, None, Some(Core::Core1), move || {
        codec::run(codec_rx)
    });

    let (start_hz, sweep_hz) = channels();
    spawn_radio(board.radio, start_hz, sweep_hz);
    // WiFi and the HTTP API, on core 0 at a low priority (only once networks
    // are saved, or the menu scans for one)
    net::start(board.modem, mac_str.to_string());
    firmware::confirm_later();

    unsafe { esp_idf_svc::sys::vTaskPrioritySet(core::ptr::null_mut(), APP_PRIORITY as u32) };
    block_on(async {
        let speaker_fut = speaker::init(board.speaker).await;

        let app_fut = app::init::<Esp>(
            app::Devices {
                mic: mic::init(board.mic),
                battery: battery::init(board.battery),
                ptt: ptt::init(board.ptt),
                knob: encoder::init(board.vol),
                screen: screen::init(board.screen),
                gps,
                settings,
            },
            mac_str,
            codec_tx,
        )
        .await;

        log::info!("All systems ready");
        join4(app_fut, speaker_fut, log_memory(), log_cpu()).await;
    });
}

/// Log memory every 5 minutes: the heap (free now, the largest block one
/// allocation can get, the least ever free), and each task's stack at its
/// fullest (the least ever free). The least-evers only move when something
/// new happens, so more often only fills the log
async fn log_memory() {
    use esp_idf_svc::sys::*;
    const MAX_TASKS: usize = 24;
    loop {
        unsafe {
            // Internal RAM only: that's what everything but the log buffer
            // allocates from. PSRAM (the log buffer) is mostly spoken for
            log::info!(
                "Heap: free {} B, largest block {} B, min ever free {} B, psram free {} B",
                heap_caps_get_free_size(MALLOC_CAP_INTERNAL),
                heap_caps_get_largest_free_block(MALLOC_CAP_INTERNAL | MALLOC_CAP_8BIT),
                heap_caps_get_minimum_free_size(MALLOC_CAP_INTERNAL),
                heap_caps_get_free_size(MALLOC_CAP_SPIRAM)
            );
            let mut tasks: [TaskStatus_t; MAX_TASKS] = core::mem::zeroed();
            let n =
                uxTaskGetSystemState(tasks.as_mut_ptr(), MAX_TASKS as u32, core::ptr::null_mut())
                    as usize;
            let mut line = heapless::String::<512>::new();
            for task in &tasks[..n] {
                let name = core::ffi::CStr::from_ptr(task.pcTaskName).to_string_lossy();
                let _ = write!(line, " {}={}", name, task.usStackHighWaterMark);
            }
            log::info!("Stack free (least ever, B):{}", line);
        }
        embassy_time::Timer::after_secs(300).await;
    }
}

/// Tasks the CPU log can follow; more are left out
const CPU_MAX_TASKS: usize = 24;

/// How often the CPU log samples, and how many samples make a log line
const CPU_SAMPLE_SECS: u64 = 1;
const CPU_SAMPLES_PER_LINE: u32 = 60;

/// One task's CPU time, as the CPU log follows it
struct TaskCpu {
    number: u32, // FreeRTOS's task number: names aren't unique
    name: heapless::String<16>,
    last_us: u32,   // its run-time counter at the last sample
    line_us: u64,   // run since the line began
    worst_pct: u32, // its busiest second since then
    least_pct: u32, // its idlest: for an idle task, the core's busiest
}

/// Log CPU use every 60s, like htop: each core's load and each busy task's
/// share of a core, averaged over the minute and in its worst 1s. The worst
/// second is what starves the codec; an average hides it. A core's load is
/// 100% less its idle task's share. Tasks under 1% both ways are left out
async fn log_cpu() {
    use esp_idf_svc::sys::*;
    // Both tables live across the sample timer's await, so in this future,
    // which is on the main task's stack: ~2KB there cost it ~4.5KB of
    // headroom (Stack free log, 2026-10-04). Allocated once, on the heap
    let mut tasks = Box::new(heapless::Vec::<TaskCpu, CPU_MAX_TASKS>::new());
    let mut snapshot: Box<[TaskStatus_t; CPU_MAX_TASKS]> = Box::new(unsafe { core::mem::zeroed() });
    let mut last_at = unsafe { esp_timer_get_time() };
    let mut line_us = 0u64;
    let mut samples = 0u32;
    loop {
        embassy_time::Timer::after_secs(CPU_SAMPLE_SECS).await;

        let n = unsafe {
            uxTaskGetSystemState(
                snapshot.as_mut_ptr(),
                CPU_MAX_TASKS as u32,
                core::ptr::null_mut(),
            )
        } as usize;
        let now = unsafe { esp_timer_get_time() };
        let sample_us = (now - last_at).max(1) as u64;
        last_at = now;
        // The first sample only finds the tasks: nothing ran "since" yet
        let priming = tasks.is_empty();
        line_us += sample_us;
        samples += 1;

        for status in &snapshot[..n] {
            // The counter is 32 bits of microseconds: it wraps every ~71
            // minutes, so take differences with wrapping
            let counter = status.ulRunTimeCounter;
            let number = status.xTaskNumber;
            match tasks.iter_mut().find(|t| t.number == number) {
                Some(task) => {
                    let ran_us = counter.wrapping_sub(task.last_us) as u64;
                    task.last_us = counter;
                    task.line_us += ran_us;
                    let pct = (ran_us * 100 / sample_us) as u32;
                    task.worst_pct = task.worst_pct.max(pct);
                    task.least_pct = task.least_pct.min(pct);
                }
                // New: counted from the next sample on
                None => {
                    let name = unsafe { core::ffi::CStr::from_ptr(status.pcTaskName) };
                    let mut task = TaskCpu {
                        number,
                        name: heapless::String::new(),
                        last_us: counter,
                        line_us: 0,
                        worst_pct: 0,
                        least_pct: u32::MAX,
                    };
                    let _ = task.name.push_str(&name.to_string_lossy());
                    let _ = tasks.push(task);
                }
            }
        }

        if priming {
            line_us = 0;
            samples = 0;
            continue;
        }
        if samples < CPU_SAMPLES_PER_LINE {
            continue;
        }
        let avg_pct = |task: &TaskCpu| (task.line_us * 100 / line_us) as u32;
        let mut line = heapless::String::<256>::new();
        // Cores: 100% less idle. Idle's idlest second is the core's busiest
        for core in ["IDLE0", "IDLE1"] {
            if let Some(idle) = tasks.iter().find(|t| t.name == core) {
                let _ = write!(
                    line,
                    " core{} {}/{}",
                    &core[4..],
                    100u32.saturating_sub(avg_pct(idle)),
                    100u32.saturating_sub(idle.least_pct.min(100))
                );
            }
        }
        let _ = write!(line, " |");
        tasks.sort_unstable_by_key(|t| core::cmp::Reverse(t.line_us));
        for task in tasks.iter() {
            let avg = avg_pct(task);
            if task.name.starts_with("IDLE") || (avg < 1 && task.worst_pct < 1) {
                continue;
            }
            let _ = write!(line, " {} {}/{}", task.name, avg, task.worst_pct);
        }
        log::info!("CPU % ({}s avg/worst 1s):{}", line_us / 1_000_000, line);

        for task in tasks.iter_mut() {
            task.line_us = 0;
            task.worst_pct = 0;
            task.least_pct = u32::MAX;
        }
        line_us = 0;
        samples = 0;
    }
}

/// The radio gets its own thread on core 1, so nothing else running can
/// delay it (on core 0 with the codec, a TX step took up to 200ms instead of
/// 75). It talks to the app only through RX_CHAN and TX_CHAN.
/// From the config: the channel we send on (the first hop channel), and
/// the channels to sweep while idle (none unless the sweep flag is on).
/// Nothing hops yet: we send on the first one only
fn channels() -> (u32, Vec<u32>) {
    let hops = air::hop_slots(
        config::START_SLOT.get() as u32,
        config::HOP_SEED.get() as u64,
        config::RX_HOPS.get() as u32,
    );
    let start_hz = air::slot_hz(hops[0]);
    log::info!("Channel: slot {} = {} Hz", hops[0], start_hz);
    if !config::SWEEP.is_on() {
        return (start_hz, Vec::new());
    }
    log::info!("Channel: sweeping slots {:?}", hops);
    (start_hz, hops.into_iter().map(air::slot_hz).collect())
}

fn spawn_radio(pins: radio::Peripherals, frequency_hz: u32, sweep_hz: Vec<u32>) {
    // The radio is created on this thread, not moved to it: created on core 0
    // and moved, it hung (src/bin/radio_timing.rs). lora-phy's futures are big.
    thread::spawn(
        c"radio",
        // 16KB overflowed with the sweep (CAD) path added (2026-10-03);
        // ~9.6KB used at worst before it (Stack free log, 2026-10-02)
        24576,
        Some(RADIO_PRIORITY),
        Some(Core::Core1),
        move || block_on(async { radio::init(pins, frequency_hz, sweep_hz).await.await }),
    );
}

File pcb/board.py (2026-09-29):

#!/usr/bin/env python3
"""Generate the open-oswst PCB."""

import subprocess
from kicad import Board

board = Board()
git_sha = subprocess.check_output(["git", "rev-parse", "--short", "HEAD"], text=True).strip()

# 70x50mm landscape, centered on A4 (297x210mm)
BX, BY = 113, 113  # board origin
BW, BH = 70, 50    # board size
INSET_LR = 5        # hole center distance from left/right edges
INSET_TB = 2.5      # hole center distance from top/bottom edges

board.add_rect(BX, BY, BW, BH)

for x in (BX + INSET_LR, BX + BW - INSET_LR):
    for y in (BY + INSET_TB, BY + BH - INSET_TB):
        board.add_mounting_hole(x, y, drill=2.2)

# Connectors along top edge — fit between drill holes (INSET_LR)
cx, cy = BX + INSET_LR + 7, BY + 4
board.add_jst_ph(cx, cy, pins=2, label="BAT",
                 pad_labels=["+", "-"], pad_nets=["VBAT", "GND"]); cx += 7
board.add_jst_ph(cx, cy, pins=2, label="SW",
                 pad_nets=["VBAT", "VSW"]); cx += 7
board.add_jst_ph(cx, cy, pins=2, label="PA",
                 pad_labels=["+", "-"], pad_nets=["VSW", "GND"]); cx += 10
# (CHNL encoder was here — dropped: its pins GPIO7/GPIO5 belong to the V4.3's
# RF front end. Channel is picked from the menu instead. Gap kept so VOL/PTT
# don't move.)
cx += 11
board.add_jst_ph(cx, cy, pins=4, label="VOL",
                 pad_labels=["A", "B", "SW", "GND"],
                 pad_nets=["VOL_A", "VOL_B", "VOL_SW", "GND"]); cx += 10
board.add_jst_ph(cx, cy, pins=2, label="PTT",
                 pad_nets=["PTT", "GND"])

# HBAT: feeds VSW out to Heltec's onboard SH1.25-2P LiPo input via an M2M pigtail.
# Heltec's battery input accepts 3.3-4.2V (per datasheet 3.2), so raw LiPo is correct here.
# Placed above SPK so VSW from BAT/SW (top of board) doesn't cross the SPK+/SPK- traces.
board.add_jst_ph(BX + 5, BY + INSET_TB + 7, pins=2, label="HBAT", angle=90,
                 pad_labels=["+", "-"], pad_nets=["VSW", "GND"])

# SPK connector on left edge (rotated 90°, routes down to AMP_SPK)
board.add_jst_ph(BX + 5, BY + INSET_TB + 14, pins=2, label="SPK", angle=90,
                 pad_labels=["-", "+"], pad_nets=["SPK-", "SPK+"])

# Heltec V4 headers — two 18-pin rows
J3_SPAN = 17 * 2.54  # 18 pins, 17 gaps
HELTEC_WIDTH = 22.86  # distance between J3 and J2 header rows
HY = BY + BH / 2 - HELTEC_WIDTH / 2 - 4  # J3 y (top row), shifted 4mm toward top-edge JSTs

board.add_header(BX + BW - 3 - J3_SPAN / 2, HY, pins=18, label="J3",
                 pad_labels=["GPIO7", "GPIO6", "GPIO5", "GPIO4", "GPIO3", "GPIO2",
                             "GPIO1", "GPIO38", "GPIO39", "GPIO40", "GPIO41", "GPIO42",
                             "GPIO45", "GPIO46", "GPIO37", "3V3a", "3V3b", "GND"],
                 # GPIO7 (FEM power), GPIO5 (FEM CTX), GPIO2 (FEM CSD) must stay
                 # unconnected: the Heltec V4.3 drives them. GPIO1 + GPIO37 are
                 # battery sense (ADC + divider enable). VOL_SW on GPIO45 is a
                 # strapping pin, safe as a switch to GND (LOW is its default).
                 pad_nets=[None, "VOL_B", None, "MIC_OUT", "VOL_A", None,
                           None, None, None, None, None, None,
                           "VOL_SW", None, None, None, None, "GND"])

# Heltec V4 J2 header (right side, pin 18→1 top to bottom)
J2_SPAN = J3_SPAN  # same 18 pins
board.add_header(BX + BW - 3 - J2_SPAN / 2, HY + HELTEC_WIDTH, pins=18, label="J2",
                 pad_labels=["GPIO19", "GPIO20", "GPIO21", "GPIO26", "GPIO48", "GPIO47",
                             "GPIO33", "GPIO34", "GPIO35", "GPIO36", "GPIO0", "RST",
                             "GPIO43", "GPIO44", "Ve_b", "Ve_a", "5V", "GND"],
                 pad_nets=[None, None, None, None, "LRC", "BCLK",
                           "DIN", None, None, None, "PTT", None,
                           None, None, "Ve", "Ve", None, "GND"])

# Board headers along bottom edge
board.add_header(BX + BW / 2, BY + BH - 9, pins=5, label="MIC",
                 pad_labels=["AR", "OUT", "GAIN", "VDD", "GND"],
                 pad_nets=[None, "MIC_OUT", None, "Ve", "GND"])
AMP_X = BX + 3 + 3 * 2.54
AMP_Y = BY + BH - 3 - 5 - 4
board.add_header(AMP_X, AMP_Y, pins=7, label="AMP", angle=180,
                 pad_labels=["Vin", "GND", "SD", "GAIN", "DIN", "BCLK", "LRC"],
                 pad_nets=["Ve", "GND", None, None, "DIN", "BCLK", "LRC"])
board.add_header(AMP_X, AMP_Y - 12.954, pins=2, label="AMP_SPK", angle=180,
                 pitch=3.5, pad_labels=["+", "-"], pad_nets=["SPK+", "SPK-"])

# Silkscreen — project name and git SHA
board.add_text(BX + BW / 2, BY + BH - 2, f"open-oswst  {git_sha}", size=0.8, thickness=0.12)

# Ground plane — GND zone covering full board, both copper layers
board.add_zone("GND", [
    (BX, BY), (BX + BW, BY), (BX + BW, BY + BH), (BX, BY + BH),
], clearance=0.25, thermal_gap=0.3, thermal_bridge_width=0.3)

board.save("open-oswst.kicad_pcb")

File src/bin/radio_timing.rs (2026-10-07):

//! Radio turnaround bench: where do the ~45ms per TX go, beyond the 61.7ms of
//! air? The app measured ~1.5ms per SPI command, where the wire time is
//! ~40µs. This finds out which part of the interrupt → wake → poll chain
//! costs it, and whether thread placement changes it.
//!
//! Sends a 26B packet every 160ms, going back to RX after each, like a relay.
//! The packet type is one nobody uses, so the other radios ignore it.
//! The radio runs in its own thread, placed by RADIO_CORE and RADIO_PRIORITY
//! (core 0 / prio 1 is where the app's radio runs today: the main task).
//! It cycles through three loads, PACKETS packets each, forever:
//!   - idle: nothing else running
//!   - codec: the real Codec2, encode + decode every 160ms. Lots of code and
//!     tables, all executed and read from flash through the shared cache
//!   - spin: a tiny loop, CPU-busy for as long as the codec took, every
//!     160ms. It fits in the cache, so it competes for the CPU like the
//!     codec but puts no pressure on the cache
//!
//! If SPI slows under codec but not under spin, it's the flash cache, not
//! scheduling. Both loads are spawned like the app's codec: no core
//! affinity, prio 5.
//!
//! Each run logs each TX step (median / max), and inside them how long SPI
//! transfers and BUSY waits took. "armed" counts BUSY waits where the pin was
//! still high, so the hal had to arm the interrupt and sleep.
//!
//! The radio is created on the thread that uses it: created on core 0 and
//! moved to a thread on core 1, it hung on its first IRQ wait. Why is not
//! known. Not GPIO routing: ESP-IDF sends every GPIO interrupt to the core
//! that enabled the first one, whichever core enables later ones.
//!
//! Build & flash: cargo build --bin radio_timing && espflash flash -p <PORT> --partition-table target/xtensa-esp32s3-espidf/debug/partition-table.bin target/xtensa-esp32s3-espidf/debug/radio_timing

use embassy_time::{Duration, Ticker};
use embedded_hal_async::digital::Wait;
use embedded_hal_async::spi::{Operation, SpiDevice};
use esp_idf_svc::hal::cpu::{self, Core};
use esp_idf_svc::hal::gpio::{Input, PinDriver, Pull};
use esp_idf_svc::hal::spi::config::Config as SpiConfig;
use esp_idf_svc::hal::spi::{SpiDeviceDriver, SpiDriver, SpiDriverConfig};
use esp_idf_svc::hal::task::block_on;
use esp_idf_svc::hal::task::thread::ThreadSpawnConfiguration;
use esp_idf_svc::hal::units::Hertz;
use lora_phy::iv::GenericSx126xInterfaceVariant;
use lora_phy::mod_params::*;
use lora_phy::sx126x::{self, Sx1262, Sx126x, TcxoCtrlVoltage};
use lora_phy::LoRa;
use open_oswst::board;
use open_oswst::devices::{fem, radio};
use open_oswst_core::codec::{self, CodecRequest, CODEC2_FRAME_SAMPLES, DECODED, ENCODED};
use open_oswst_core::codec::{FRAMES_PER_PACKET, PAYLOAD_BYTES};
use open_oswst_core::packet;
use std::sync::atomic::{AtomicU32, AtomicU8, Ordering};
use std::time::Instant;

/// Where the radio thread runs
const RADIO_CORE: Core = Core::Core0;
const RADIO_PRIORITY: u8 = 1;
/// Packets per run: ~6.4s each
const PACKETS: usize = 40;

type Iv =
    GenericSx126xInterfaceVariant<PinDriver<'static, esp_idf_svc::hal::gpio::Output>, TimedPin>;
type Radio = LoRa<
    Sx126x<TimedSpi<SpiDeviceDriver<'static, SpiDriver<'static>>>, Iv, Sx1262>,
    embassy_time::Delay,
>;

/// What else is running: one of the LOAD_ values
static LOAD: AtomicU8 = AtomicU8::new(LOAD_IDLE);
const LOAD_IDLE: u8 = 0;
const LOAD_CODEC: u8 = 1;
const LOAD_SPIN: u8 = 2;
const LOADS: [(u8, &str); 3] = [
    (LOAD_IDLE, "idle"),
    (LOAD_CODEC, "codec"),
    (LOAD_SPIN, "spin"),
];
/// How long one encode + decode took, last time: the spin load copies it
static CODEC_US: AtomicU32 = AtomicU32::new(0);

fn main() {
    esp_idf_svc::sys::link_patches();
    esp_idf_svc::log::EspLogger::initialize_default();
    log::info!("radio_timing starting");

    let board = board::take();
    let _fem = fem::init(board.fem);

    // The codec, spawned like the app spawns it (before any spawn config is set)
    let (codec_tx, codec_rx) = std::sync::mpsc::sync_channel::<CodecRequest>(2);
    std::thread::Builder::new()
        .name("codec".into())
        .stack_size(32768)
        .spawn(move || codec::run(codec_rx))
        .unwrap();
    std::thread::Builder::new()
        .name("feeder".into())
        .stack_size(8192)
        .spawn(move || feed_codec(codec_tx))
        .unwrap();
    std::thread::Builder::new()
        .name("spin".into())
        .stack_size(4096)
        .spawn(spin)
        .unwrap();

    ThreadSpawnConfiguration {
        name: Some(c"radio"),
        priority: RADIO_PRIORITY,
        pin_to_core: Some(RADIO_CORE),
        ..Default::default()
    }
    .set()
    .unwrap();
    // std's stack size wins over the spawn config's, so it's set here. The
    // lora-phy futures are big: the app runs them on the 64KB main stack
    let radio_pins = board.radio;
    std::thread::Builder::new()
        .stack_size(32768)
        .spawn(move || block_on(run(radio_pins)))
        .unwrap();
    ThreadSpawnConfiguration::default().set().unwrap();

    loop {
        std::thread::sleep(std::time::Duration::from_secs(1));
    }
}

/// The radio thread: a run under each load in turn, forever.
async fn run(radio_pins: radio::Peripherals) {
    let mut lora = new_radio(radio_pins).await;
    log::info!(
        "LoRa radio initialized, thread on core {:?} prio {}",
        cpu::core(),
        RADIO_PRIORITY
    );
    loop {
        for (load, name) in LOADS {
            LOAD.store(load, Ordering::Relaxed);
            let rows = bench(&mut lora).await;
            report(name, &rows);
        }
    }
}

/// Same radio setup as devices::radio, but with the SPI device and the BUSY
/// pin wrapped so each transfer and wait is timed.
async fn new_radio(p: radio::Peripherals) -> Radio {
    let spi = SpiDeviceDriver::new_single(
        p.spi,
        p.sck,
        p.mosi,
        Some(p.miso),
        Some(p.nss),
        &SpiDriverConfig::new(),
        &SpiConfig::new().baudrate(Hertz(2_000_000)),
    )
    .unwrap();
    let reset = PinDriver::output(p.reset).unwrap();
    let dio1 = TimedPin {
        pin: PinDriver::input(p.dio1, Pull::Floating).unwrap(),
        is_busy: false,
    };
    let busy = TimedPin {
        pin: PinDriver::input(p.busy, Pull::Floating).unwrap(),
        is_busy: true,
    };
    let rf_switch_tx = p.rf_switch_tx.map(|pin| PinDriver::output(pin).unwrap());
    let iv = GenericSx126xInterfaceVariant::new(reset, dio1, busy, None, rf_switch_tx).unwrap();

    let config = sx126x::Config {
        chip: Sx1262,
        tcxo_ctrl: Some(TcxoCtrlVoltage::Ctrl1V7),
        use_dcdc: true,
        rx_boost: false,
    };
    LoRa::new(
        Sx126x::new(TimedSpi(spi), iv, config),
        false,
        embassy_time::Delay,
    )
    .await
    .unwrap()
}
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

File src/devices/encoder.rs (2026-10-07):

//! Rotary encoder with push switch. Hands out turn, press and release events;
//! knows nothing about what they mean.
//!
//! `next()` is cancel-safe: all state lives in the struct, and each call first
//! catches up on anything that changed while nobody was awaiting it, so it can
//! sit in a `select` that drops it.

use embassy_futures::select::{select, select3, Either};
use embassy_time::Timer;
use embedded_hal_async::digital::Wait;
use esp_idf_svc::hal::gpio::{AnyIOPin, Pull};

use super::irq_pin::IrqPin;

/// Switch must hold steady this long to count as a press or release
const DEBOUNCE_MS: u64 = 15;

/// Quadrature transitions per detent (one "click" of the knob)
const STEPS_PER_DETENT: i8 = 4;

pub struct Peripherals {
    pub a: AnyIOPin<'static>,
    pub b: AnyIOPin<'static>,
    pub sw: AnyIOPin<'static>,
}

pub use open_oswst_core::devices::knob::Event;

pub struct Encoder {
    a: IrqPin,
    b: IrqPin,
    sw: IrqPin,
    phase: u8,     // gray-code position 0..4
    steps: i8,     // transitions accumulated toward the next detent
    pressed: bool, // debounced switch state
}

/// Configure the pins. Common ties to GND, so all three use internal pull-ups.
pub fn init(p: Peripherals) -> Encoder {
    let a = IrqPin::new(p.a.into(), Pull::Up);
    let b = IrqPin::new(p.b.into(), Pull::Up);
    let sw = IrqPin::new(p.sw.into(), Pull::Up);
    let phase = gray_phase(a.is_high(), b.is_high());
    let pressed = sw.is_low();
    Encoder {
        a,
        b,
        sw,
        phase,
        steps: 0,
        pressed,
    }
}

impl Encoder {
    /// Wait for the next turn (one detent), press or release.
    pub async fn next(&mut self) -> Event {
        loop {
            if let Some(event) = self.update_quadrature() {
                return event;
            }
            if self.sw.is_low() != self.pressed {
                if let Some(event) = self.debounce_switch().await {
                    return event;
                }
                continue;
            }
            let _ = select3(
                self.a.wait_for_any_edge(),
                self.b.wait_for_any_edge(),
                self.sw.wait_for_any_edge(),
            )
            .await;
        }
    }

    /// Advance the gray-code state machine; emit an event per full detent.
    fn update_quadrature(&mut self) -> Option<Event> {
        let phase = gray_phase(self.a.is_high(), self.b.is_high());
        match (phase + 4 - self.phase) % 4 {
            1 => self.steps += 1,
            3 => self.steps -= 1,
            _ => {} // no change, or skipped a state (bounce) — ignore
        }
        self.phase = phase;
        if self.steps >= STEPS_PER_DETENT {
            self.steps -= STEPS_PER_DETENT;
            Some(Event::Cw)
        } else if self.steps <= -STEPS_PER_DETENT {
            self.steps += STEPS_PER_DETENT;
            Some(Event::Ccw)
        } else {
            None
        }
    }

    /// Wait until the switch holds steady, then report a press or release if
    /// it changed.
    async fn debounce_switch(&mut self) -> Option<Event> {
        // Each edge restarts the stability window
        while let Either::First(_) = select(
            self.sw.wait_for_any_edge(),
            Timer::after_millis(DEBOUNCE_MS),
        )
        .await
        {}
        let pressed = self.sw.is_low();
        if pressed == self.pressed {
            return None;
        }
        self.pressed = pressed;
        Some(if pressed {
            Event::Press
        } else {
            Event::Release
        })
    }
}

/// Position in the CW sequence 00 → 10 → 11 → 01.
fn gray_phase(a: bool, b: bool) -> u8 {
    match (a, b) {
        (false, false) => 0,
        (true, false) => 1,
        (true, true) => 2,
        (false, true) => 3,
    }
}

impl open_oswst_core::devices::knob::Knob for Encoder {
    async fn next(&mut self) -> Event {
        Encoder::next(self).await
    }
}

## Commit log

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2026-04-23 Add VU meter from mic (MAX9814 on GPIO7) and show MAC on OLED
    Replace "LORAUDIO" title with device MAC address for board identification.
    Sample mic via ADC between 50ms RX windows and display peak level as
    a bar at the bottom of the OLED.
    [main.rs]
2026-04-23 Switch to DMA continuous ADC for mic, three-way async select
    Replace polling ADC loop with esp-idf continuous ADC driver (8kHz DMA).
    Main loop uses select3(rx_packet, ptt_button, mic_buffer_ready) — all
    interrupt-driven, zero polling, no gaps in RX coverage. VU meter updates
    from DMA buffer peak detection.
    [main.rs]
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2026-04-23 Extract radio_task and app_task into async fns with concrete types
    Replace inline async blocks with proper async fn declarations using
    concrete type aliases (Radio, Display, Iv). Bump main task stack to
    32KB to accommodate the larger composed future.
    [main.rs]
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2026-04-24 Pack 4 Codec2 frames per LoRa packet for real-time voice
    A single 6-byte Codec2 frame takes ~61ms to send at SF8/125kHz but
    only carries 40ms of audio — playback can never keep up. Packing 4
    frames per packet (24 bytes, 160ms audio, ~113ms air time) gives 47ms
    of slack per packet.
    TX batches recording on PTT release, then encodes and sends multi-frame
    packets. RX unpacks all frames per packet, buffers one packet's worth
    (160ms jitter buffer), then streams to I2S. Voice is now intelligible
    end-to-end over LoRa.
    [app.rs]
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2026-04-24 Use non-blocking I2S write to avoid stalling event loop
    Drop audio frames instead of blocking when DMA buffer is full.
    Prevents missed RX packets and button events during playback bursts.
    [app.rs]
2026-04-24 WIP: Add seq tracking and refactor RX path for sequence buffer
    - Add cur_txid and last_played_seq state for packet ordering
    - Compute seq diff (signed mod-16 distance from expected)
    - Extract decode_and_play() and draw_rx_audio_screen() helpers
    - Early-return on unexpected packet size (railroad pattern)
    - Use non-blocking I2S write (5ms timeout) to avoid stalling event loop
    No behavior change yet — all packets still play immediately.
    [app.rs]
2026-04-24 Decode on arrival, buffer stereo PCM in seq_buf
    Decode Codec2 frames immediately when packets arrive and store decoded
    stereo PCM (~5KB per packet) in the sequence buffer. Drain loop now
    just writes pre-decoded audio to I2S — no decode blocking during
    playback. Add 500ms RX timeout to auto-reset txid lock. Tighten
    seq window to 0..=2 ahead.
    [app.rs]
2026-04-24 Add EOT packet, pkt_type check, and RX timeout
    TX sends header-only (2-byte) packet on PTT release as end-of-transmission
    signal. RX detects header-only packets and resets immediately instead of
    waiting for 500ms timeout (kept as fallback). Reject non-voice pkt_type
    with verbose header logging.
    Note: intermittent choppiness observed during testing — may be RF related,
    not yet root-caused.
    [app.rs]
2026-04-24 Add squelch tail white noise on end-of-transmission
    Play 250ms of fading white noise when an EOT packet is received,
    mimicking the classic radio squelch tail sound.
    [app.rs]
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2026-09-23 Add screen module: app-agnostic, double-buffered OLED on its own thread
    screen.rs owns the SSD1306 (reset, I2C, init) and knows only pixels.
    Callers draw into a Frame (page-layout 1bpp buffer implementing
    embedded-graphics DrawTarget) and hand it to Screen::show. A dedicated
    thread pushes frames over I2C, so the ~90ms flush no longer stalls the
    app loop — previously it blocked on every RX voice packet.
    Latest frame wins: frame() never blocks, reclaiming a still-pending
    frame if there is one, and show() replaces rather than queues.
    Adds src/lib.rs so bins can share modules; hello_world and the main
    app both use the screen module. Also fall back to default config when
    the NVS config namesp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
    [app.rs, main.rs]
2026-09-23 case: bring over the fixed case from the footprints branch
    case.py, case.step and case.stl only. The footprints PCB changes
    (mirrored MIC pads) stay on that branch.
    [case.step, case.stl]
2026-09-23 board: one shared pin map for every app; move radio + speaker into lib
    board::take() takes the peripherals, powers Vext, and hands out each
    subsystem's pins for the PCB v2. main and hello_world now get their
    pins from it, so they can't drift from the bringup tests again.
    That drift is why RX showed RSSI but played nothing: the main app was
    still on the breadboard pins (I2S on GPIO 3/4/5, mic on GPIO7). Now
    speaker is BCLK 47 / DIN 33 / WS 48 and mic is GPIO4, matching
    speaker_test and mic_test. Audio verified end to end on two radios.
    radio and speaker move into the lib with their channels (RX_CHAN,
    TX_CHAN, SPK_FRAMES, SPK_REQ). Also cargo fmt --all.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
    [app.rs, board.rs, main.rs]
2026-09-23 Fix clippy warnings
    mic_test: drop unused import, iterate the ADC slice directly.
    audio_test: drop needless mut. codec: allow large_enum_variant on
    CodecResponse — it only sits in a single-slot channel, so boxing
    would add a heap alloc per packet for nothing.
    [codec.rs]
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2026-09-24 app: pipeline TX so the mic never goes undrained
    The TX loop captured a packet, then blocked on the ~128ms encode, while
    the ADC's 80ms DMA buffer overflowed: ~48ms of audio lost per packet,
    and packets left every ~200ms for 160ms of audio. The receiver ran dry
    every packet, heard as small dropouts.
    Now the codec thread encodes packet N while N+1 is captured; packets go
    out every 160ms with no encoder wait. With the RX jitter buffer this is
    intelligible end to end on two radios.
    Also: real packets-sent count (was the seq, which wraps at 16), and
    warnings for encoder-behind, speaker underrun and speaker queue drops.
    [app.rs]
2026-09-24 app: TX pipeline as join(capture N+1, encode+send N)
    Replaces the encoding flag and collect-previous-first ordering with an
    explicit two-stage join each pass. Pulls out voice_header,
    capture_packet and encode_and_send helpers; the encoder-behind warning
    now fires when encode+send outlasts a 160ms packet.
    Also reorders app.rs in execution order: init and App at the top, free
    helpers at the bottom. Verified on two radios.
    [app.rs]
2026-09-24 Menus on the VOL encoder: Lock and Repeater
    Clicking the VOL knob opens a nested menu. Every list has an implicit
    Back at the top, where the cursor starts, so stray clicks only back
    out. Turning moves an inverted highlight (clamped at the ends); the
    current value of a setting is marked with *. Lock ignores PTT (the
    menu still opens, to unlock); Repeater flips IS_REPEATER in memory.
    While the menu is open the radio only menus: audio and RX stop and
    packets received meanwhile are dropped.
    devices/encoder.rs: cancel-safe next() -> Cw/Ccw/Click, gray-code
    quadrature (4 steps per detent) and 15ms switch debounce. menu.rs: a
    static item tree plus a stack of levels. board hands out vol on
    GPIO3/2/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
    [app.rs, board.rs, encoder.rs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]
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2026-09-24 menu: save Repeater to NVS so it survives a reboot
    main opens the config namespace read-write (which also creates it on
    unprovisioned boards) and hands it to the app; choosing Repeater in
    the menu writes the repeater key. If the partition won't open, settings
    still apply but aren't saved. Lock stays in memory only.
    [app.rs, main.rs]
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2026-09-29 Free GPIO1 for battery sense: VOL_SW moves to GPIO45
    GPIO1 is the Heltec V4's battery ADC (divider enabled by GPIO37), but
    VOL_SW sat on it. GPIO45 is a strapping pin, safe as a switch to GND
    since LOW is its default.
    batt_probe verified both on the bench (A4:CB:8F:A2:0F:5C and a bare
    V4.3 F8:5B:1B:A2:C8:48): GPIO1 reads ~850 mV -> 4.37 V with GPIO37 HIGH
    and ~30 mV with it LOW; GPIO45 reads 1 open, 0 grounded, and the board
    boots normally with it grounded through a reset.
    board.rs follows the new PCB. On today's boards VOL_SW is still wired
    to GPIO1, but their encoder harnesses stay unplugged until the respin.
    [batt_probe.rs, board.py, board.rs]
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2026-09-30 Persistent text logs on LittleFS, written only while the air is quiet
    For field debugging at the edge of range, where serial isn't available.
    Storage:
    - partitions.csv: factory 15.6MB -> 4MB (the app is ~580KB), new 11.6MB
    `storage` partition. `open-oswst` settings stay at 0xfad000. Boards
    need one USB flash with the new table.
    - devices/storage.rs mounts it as LittleFS at /data (the joltwallet/littlefs
    component), chosen over FAT for power-cut safety. Then plain std::fs.
    - bin/storage_test: measured worst flash stall at 18.5ms (1KB write+fsync).
    Logging:
    - logger.rs replaces EspLogger: each line goes to serial at once, same
    format, and into a 48KB RAM buffer. It never writes flash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
    [partitions.csv]
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2026-09-30 GPS: log time and position, show them on screen
    For range testing: log lines carry real UTC and position, so a ride can
    be mapped packet by packet.
    - devices/gps.rs: the L76K on the Heltec GNSS connector. A thread reads
    NMEA (checksum-verified RMC + GGA) and keeps the latest fix; latest()
    is None once it's been quiet 3s. Fix's Display is the log format:
    2026-09-30T20:55:46Z 40.54403,-105.09197 sats=6
    - board.rs: GPS on UART1, ESP RX = GPIO39 / TX = GPIO38 (Meshtastic's
    variant.h comments read the other way and give silence), power GPIO34
    (active LOW), reset GPIO42, wake GPIO40
    - app.rs: housekeeping logs the fix every 10s and at once when a position
    is gained or lost. Screens ge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
    [app.rs, board.rs, gps.rs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]
2026-09-30 Split the app into a hardware-free `core` crate, behind device interfaces
    Step 1 of running radios on the desktop. No behaviour change: both boards
    flashed and the echo test sounds the same.
    - core/ (open-oswst-core): app, codec, echo, logger, menu, mode, packet
    moved here (git mv), plus devices/ interfaces:
    - radio, speaker, screen: the existing channels / frame handoff, moved
    as-is. The screen's FREE/READY pool is shared by any driver via
    next_to_show()/shown().
    - gps: Fix, its log format, and the NMEA parser, now with 6 unit tests.
    - mic, ptt, knob, settings: small traits.
    - platform::Platform bundles them, so the app is App<P: Platform>.
    - logger takes its clock, log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
    [app.rs, codec.rs, encoder.rs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]
2026-09-30 Extract RX sequencing into rx_buffer, with tests proving two audio bugs
    The dog-walk logs showed the handheld's radio receiving most echo
    packets while the app played far fewer. RxBuffer is App's reorder logic
    moved out verbatim (lock onto a talker, judge seq, insert decoded audio,
    feed the speaker), so it can be tested; App now uses it. Behaviour is
    unchanged: both boards flashed, echo sounds the same.
    Two tests intentionally FAIL, proving the theories:
    - a_lost_packet_costs_one_gap: losing packet 4 plays 0 1 2 3 . . 8 ...
    The speaker never skips a missing seq (the skip is commented out), so
    5 and 6 pile up until 7 looks "unexpected" and resets. One lost packet
    costs 640ms, not 160ms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
    [app.rs]
2026-09-30 rx_buffer: drop an impossible seq instead of resetting on it
    At low SNR a corrupt header can slip past the radio's CRC; one arriving
    with an impossible seq reset the whole buffer, throwing away audio that
    had already arrived. Now it's dropped as corrupt (Verdict::Corrupt), and
    only RESYNC_AFTER = 3 impossible seqs in a row, meaning we really have
    lost track, reset the buffer (Verdict::Resync). Log lines say which.
    a_corrupt_packet_costs_only_itself now passes; new losing_track_resyncs
    covers the resync. All 10 core tests pass.
    [app.rs]
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2026-10-02 app: no squelch tail on RX timeout, only on a received EOT
    At the edge of range the RX timeout fires in the middle of a broken-up
    transmission, so the tail played between fragments and sounded like the
    talker had let go. The EOT packet still plays it.
    [app.rs]
2026-10-02 app: never flush logs to flash on a repeater
    A flash write stalls the chip; a packet landing in the stall misses its
    relay slot. The RAM buffer fills and then drops lines instead.
    [app.rs]
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2026-10-02 radio_timing: fix doc lint, default back to the app's placement (core 0, prio 1)
    [radio_timing.rs]
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2026-10-02 radio: log RADIO IRQ STALL when a packet's end IRQ never comes
    The CSMA wait now gives up 100ms after the preamble (a stopgap: it used to
    wait until another radio sent, ~2s). When it does, it logs DIO1's level,
    the IRQ register as lora-phy reads it, RSSI, and every IRQ the wait
    handled with its time, to tell a chip that never finished the packet from
    a flag our clear wiped or an IRQ we missed. relay-test.py prints every
    stall first, and flags a split echo recording. TODOs where packets are
    lost: the waited-for packet is dropped, the IRQ clear can wipe a fresh
    RxDone, and a talker locks onto its own relayed txid.
    [app.rs]
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2026-10-02 Keep the TCXO running; discard RX while transmitting
    radio: Sx126x::with_oscillator_kept_on() (our lora-phy fork). Relays are
    no longer late: margin -8.0 -> +13.3ms median, 0 of 43 late, and the
    desk path handheld -> repeater -> echo -> handheld got 43/43 at each hop.
    app: on_ptt and replay_echo now drop packets heard while transmitting, as
    they arrive. With the faster turnaround the handheld fully receives the
    repeater's relays of its own packets; nobody read RX_CHAN during PTT, so
    it filled, the radio blocked handing over the next one, and the app
    blocked sending to the radio: PTT froze after 4 packets.
    [app.rs]
2026-10-02 Run the radio on its own thread: core 1, priority 10
    The codec could take core 0 from the radio (bench: a TX step 75 -> 200ms).
    Relay test: the talker's back_to_rx went from sd 5.6ms (max 20.7) to sd
    0.3 (max 9.0), and the handheld's speaker underruns from 39 to 0. 93/93
    packets on every hop over two PTTs, no relay late.
    Also corrects radio_timing's comment: why the radio hangs when moved
    cores after creation is unknown; it isn't GPIO interrupt routing.
    [main.rs, radio_timing.rs]
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2026-10-02 app: a repeater shows "Repeating" while it relays
    With the last packet's RSSI and SNR, drawn after the relay is queued so it
    doesn't delay it. Back to the listening screen on EOT or timeout (the idle
    screen only redraws on a GPS change, and a repeater has no GPS). Without
    it there was no way to see a repeater on battery working.
    [app.rs]
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2026-10-03 WiFi and an HTTP API: status, logs, config and OTA without USB
    net.rs joins the first network from config.toml that's in range (and
    rejoins), announces oswst-XXXX.local and _oswst._tcp over mDNS, and stays
    off entirely when no networks are configured. http.rs serves GET /status,
    GET /logs and /logs/NNNN.txt, GET/PUT /config (checked, atomic), POST /ota
    (streamed into the spare slot) and POST /reboot. No auth: the WiFi
    password is the security. Both run on core 0 at low priority.
    Room for it: WiFi/lwIP code kept out of IRAM (that RAM is the heap's on
    the S3), lean WiFi buffers, log buffer 48 -> 16KB, main stack 24 -> 20KB.
    Heap with WiFi up: ~55KB free, handheld minimum 26KB under PTT.
    Veri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
    [board.rs, main.rs]
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2026-10-03 FEC candidates and a LoRa link simulator to compare them
    core/src/fec: two ways to fill a 72-byte packet (SF7/250k, same ~62 ms
    on air as today's 26 bytes at 125k), plus our own CRC-8:
    - A, QMesh's scheme: RS(35,27) + rate-1/2 K=7 convolutional code (hard
    Viterbi) + 24x24 bit interleaver
    - B, Reed-Solomon only: RS(72,27), fixes any 22 bad bytes
    Fixed arrays, no allocation, ready for the firmware.
    core/examples/fec_sim: a symbol-level LoRa modem (Hamming, diagonal
    interleaver and Gray mapping as in gr-lora_sdr; symbol counts match
    Semtech's airtime formula) over white noise or noise bursts.
    Result: in white noise the ~3 dB of coding gain is exactly what 250 kHz
    costs, so net ~0 dB. In (gu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
    [main.rs]
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2026-10-03 Log playback timing per received transmission
    One line at each transmission's end (EOT or RX timeout), to see how close
    playback came to a gap:
    Playback: 40 packets, codec p50/max 67.4/70.7ms, wait p50/max
    68.5/71.8ms, queued min/p50 0/2 frames, underruns 0 (0ms)
    - codec: the codec thread's time per decode (it now reports it back)
    - wait: the app's wait for each decoded packet
    - queued: speaker frames left when each decoded packet arrived (0 = about
    to run dry; the first packet is left out, playback starts with it)
    - underruns: counted by the speaker driver (speaker::note_underrun)
    core/src/playback_timing.rs, 3 KB of fixed arrays allocated once on the
    heap: inside App it overflowed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
    [app.rs, codec.rs]
2026-10-03 App + speaker at priority 10; codec pinned to core 1
    The main task (app + speaker, core 0) ran at priority 1, below the
    codec, screen, GPS and HTTP server (5), any of which could delay the
    speaker. Now 10, level with the radio on the other core; only WiFi and
    the hal's IsrReactor (11) come first. The codec moves to core 1, away
    from the app, speaker and WiFi; the radio there still outranks it.
    Measured on the desk first (WiFi + repeater on, 3 PTTs each, with the
    Playback timing line), after the double-decode fix: current placement,
    priority 7, codec on core 1 and app + speaker on core 1 all gave 0
    underruns per replay, wait p50 ~68 ms, 2 frames queued. Placement made
    no measurable differenc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
    [main.rs]
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2026-10-03 firmware.bin over WebDAV, and app rollback
    PUT /firmware.bin installs a new app (the old POST /ota, same code: into
    the spare OTA slot, checked, reboot). GET /firmware.bin downloads the
    one running, read from its slot: a backup, or the same build for
    another radio. It's listed in the WebDAV root next to config.toml and
    logs/. POST /ota is gone.
    Rollback (CONFIG_BOOTLOADER_APP_ROLLBACK_ENABLE): a new app boots
    "pending" and must run a minute (src/firmware.rs confirms it); if the
    radio reboots before that, the bootloader goes back to the previous
    app. /status shows firmware_state (valid / pending). A bootloader
    setting: each radio needs one USB flash to get it (handheld and echo
    done; the rep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
    [main.rs]
2026-10-03 Set the clock from GPS and NTP; real file dates in WebDAV
    The system clock (time(), and the dates LittleFS stamps on every file)
    started at 1970 on every boot and nothing set it. Now src/clock.rs sets
    it, whichever comes first:
    - the GPS, as soon as it reports a UTC date and time (long before a
    position fix; ~0.5 s, NMEA without PPS). Dates before 2024 are ignored:
    receivers report defaults before they've heard the satellites
    - NTP (ESP-IDF's SNTP, pool.ntp.org), started with WiFi; once it syncs
    it owns the clock and re-checks hourly. The GPS never overrides it
    A log line marks it ("Clock: set from GPS/NTP, <UTC>"), tying the log's
    uptime to real time even without a position.
    core/src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
    [gps.rs]
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2026-10-04 Settings registry: every setting and flag declared in config.rs
    Each setting is a global atomic, declared once with its type, default,
    when a change applies (boot or live), whether it's saved, and whether
    radios must agree on it. Flags are settings in the file's [flags] table.
    Boot loads them all, logs every value and a profile code of the
    must-match ones, and warns about keys it doesn't know. The WebDAV
    config check goes through the registry. mode moves onto it.
    [app.rs, main.rs]
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2026-10-04 Logging: fewer periodic lines; CPU log tables off main's stack
    Each log line costs a flash write that stalls both cores, so the periodic
    lines that rarely change are logged less often (walk 2026-10-04, ~470KB
    per radio): GPS every 30s (was 10; ~40m walking), CPU every 60s (was 10;
    the worst 1s is kept), heap and stack every 5 minutes (was 30s: they're
    mostly least-evers). WiFi logs only when it changes: the first failed
    search, then joined or lost (was "none joined" on every scan, ~20s apart
    away from home). Per-packet and sweep lines unchanged.
    The CPU log's task tables lived across its await, in a future on the
    main task's stack: main had 4.9KB free, now 9.0KB (was 9.1-9.7 before
    the CPU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
    [app.rs, main.rs]
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2026-10-04 Screen: WiFi line is the network's name, then the end of the IP
    Was "WiFi: <name>". Users know their own network, so the line is now the
    name on the left (cut short if need be) and the end of the radio's
    address on the right, for reaching it: the last two bytes when they fit
    beside the whole name (".0.240"), else the last one (".240"). Off and
    searching read as before. Network::Joined carries the address
    (net.rs, from the join); the line is built in core with tests.
    Flashed to all three over USB; the user checked the screens. Display
    only, so no relay test.
    [app.rs]
2026-10-04 End packets say who and where; the screen shows who we last heard
    Every transmission now ends with an end packet (EOT) carrying the
    sender's name and position: our 2-byte header, latitude and longitude in
    3 bytes each (~1.2m / ~2.4m; a reserved latitude means no fix), then the
    name (UTF-8, up to 18 bytes), zero-padded to 26 bytes: a voice packet's
    size and air time, so it fits a repeater's slot like one. Two end types
    (3 voice, 4 echo) so echo stations never replay a replay. A repeater
    relays the talker's end unchanged; an echo station ends its replay with
    its own, so the walker learns how far away the station is.
    Packet types are a #[repr(u8)] enum (PacketType); unknown bits are logged
    and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
    [app.rs, gps.rs, radio_timing.rs]
2026-10-04 Follow a transmission on two channels: each packet and its relay
    The walk of 2026-10-04 PM: with the repeater up, a receiver locked onto
    whichever copy's wake it caught first, and often that was the weak
    direct one (return 27-53%, SNR 1-4) while the repeater's relay was ~40dB
    stronger on the next channel (85-96% when locked there).
    The slot timing is fixed, so once a transmission is ours a receiver now
    hears both copies of every packet: the packet on channel a (the talker:
    channel 0 while tx_hops is 0), then 6ms later it moves to b = a+1 for the
    repeater's relay (which starts ~8.5ms after the packet; its preamble
    lasts ~12ms), then back to a 10ms before the next slot. Every packet that
    ends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
    [app.rs]
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2026-10-04 GPS progress on screen and in the log; screen time from the system clock
    The screen's "No fix, N sats" counted satellites used in a fix (GGA): 0
    until there is one, so it never showed progress (user: "never seen a
    non-zero count"). Now "No fix, used/in view": in view (GSV, per system:
    GPS, BeiDou, GLONASS) climbs as the GPS acquires, so you can see a fix
    coming before unplugging. The log's GPS line reads sats=used/in view
    (range-report's sats=(\d+) still reads used).
    The GPS thread asks the GPS for its firmware version at boot ($PCAS06,0)
    and logs its TXT lines once per change: AT6558R, URANUS5 V5.3.0.0, MO=GB;
    ANTENNA OPEN (normal for the passive ceramic patch). Proves our transmit
    line re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
    [app.rs, gps.rs]
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
